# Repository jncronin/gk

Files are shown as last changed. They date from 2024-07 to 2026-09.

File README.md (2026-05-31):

# gk and gkos #

This respository provides PCB schematics, firmware and debugging support for the gkv4 handheld game console and its operating system, gkos.  For the original STM32H7S7-based gk, see [README-v3.md](README-v3.md).

gkv4 represents a significant upgrade over the original gk with improved speed, a bigger screen, more gamepad buttons and hardware-accelerated 3D rendering.

[Videos of the gkv4 in action](https://www.youtube.com/playlist?list=PLvXUUReQ2h1UtwOlHrIKgTddPxBIt5pAU)

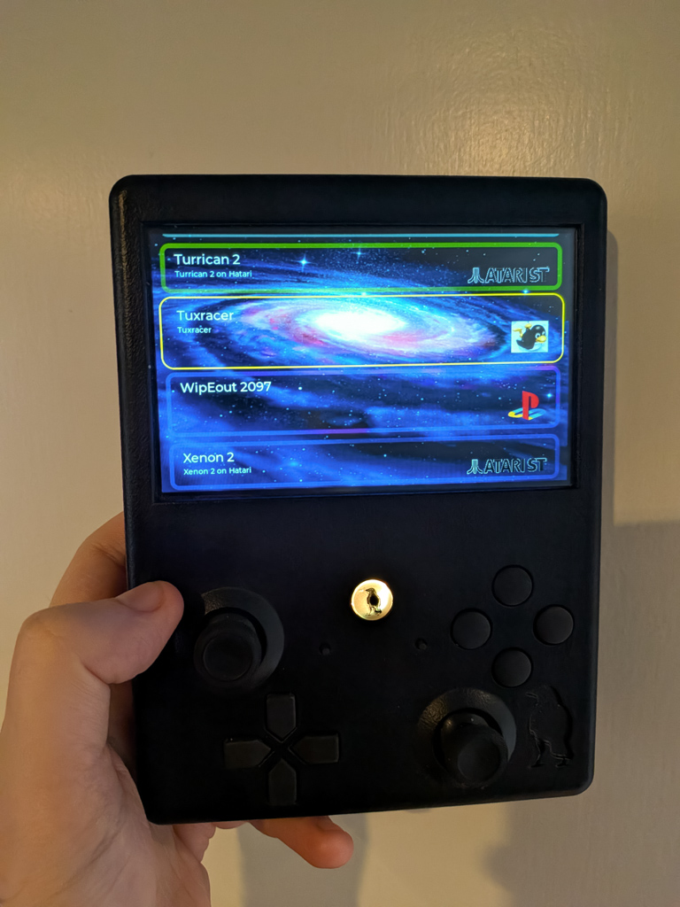
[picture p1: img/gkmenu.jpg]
An image of the gk showing its menu screen


## Overview ##

gkv4 is a small, battery powered handheld gaming console running on a STM32MP2 MPU (dual Cortex-A35 cores with additional Cortex-M33 core).  It runs a custom OS called gkos which allows near-instantaneous (MCU-like) cold boot times but is powerful enough to run most POSIX userspace applications.  See <https://github.com/jncronin/gk-userland> for the userland support including cross GCC toolchains and useful libraries.

Game/emulator support:
- Mednafen for NES, SNES, SMS, MD and Lynx support
- Hatari for Atari ST
- PCSX_rearmed for PS1
- Mupen64plus (see fork at <https://github.com/jncronin/mupen64-combined>) for N64 (GPU-accelerated)
- Atari++ for Atari XL
- DOSBox-X (achieves 25000 cycles/second, 199561 parrots, 74 XT on speedtst.com, roughly 486 50 MHz equivalent)
- Native ports of:
    - Neverball/neverputt (GPU-accelerated with tilt support)
    - Tuxracer (GPU-accelerated)
    - Doom (sdl2-doom)
    - Quake (ChocolateQuake)
    - Descent (ChocolateDescent)
    - koules

## Hardware Specifications ##

PCBs, schematics and case STL files are available in <https://github.com/jncronin/gk/tree/main/gk-pcbv4>.

- STM32MP255D processor with variable clock rate (defined on a per-game basis).  Debug and trace ports exposed.
- LPDDR4 RAM (1 GiB in current version)
- Lithium ion battery (10,000 mAH in current version) with USB-C charging via BQ25601, state of charge monitoring via MAX17048 and current sensing via INA236
- 800x480 5 inch touchscreen (ER-TFT050-6).  Hardware scaling support via STM32MP2 LTDC peripheral.
- Micro SD for storage with voltage switch support
- Wifi/Bluetooth module attached via M.2 E-key interface (e.g. EAR00389 module)
- Gyrometer/accelerometer + optional magnetometer for tilt interface
- Headphone + internal speaker audio out via TAD5112
- Multiple controls including:
    - Left and right analog sticks (programmable as digital on per-game basis)
    - ABXY + DPAD buttons
    - Start + select buttons
    - Analog throttle controller
    - Volume up/down (can be programmed as additional game inputs)
    - Menu button (opens OSD)
    - Left/right trigger + bumper buttons on back of device
- Battery backup for RTC

Total current draw is heavily dependent on screen brightness but is typically 1.5W or less at full CPU + GPU load with medium brightness, and max ~2W at full brightness.

## Software ##

gkos is a custom OS written from scratch in C++.  It is available in the <https://github.com/jncronin/gk/tree/main/Firmware-v4> directory.  Features:

- Armv8-A SMP scheduler with multiple active processes + threads
- Syscall interface with wrappers for most POSIX functions
- High resolution (10 ns precision) timer provided to games
- pthread support including threads, mutexes, semaphores, conditions, rwlocks and barriers
- A port of the etnaviv GPU driver allowing hardware-accelerated OpenGL
- Driver for Infineon CYW43439 chipset and IPv4 network stack
- SD card (with UHS-I mode support) with Ext4 (Lwext4) and FAT (fatfs) drivers
- USB driver allowing the device to present itself as a mass storage device to allow provisioning the internal SD card
- Offloading of all input tasks, including tilt sensor and touch screen filtering, to Cortex-M33 core

## Examples

Tuxracer using the GPU for rendering:

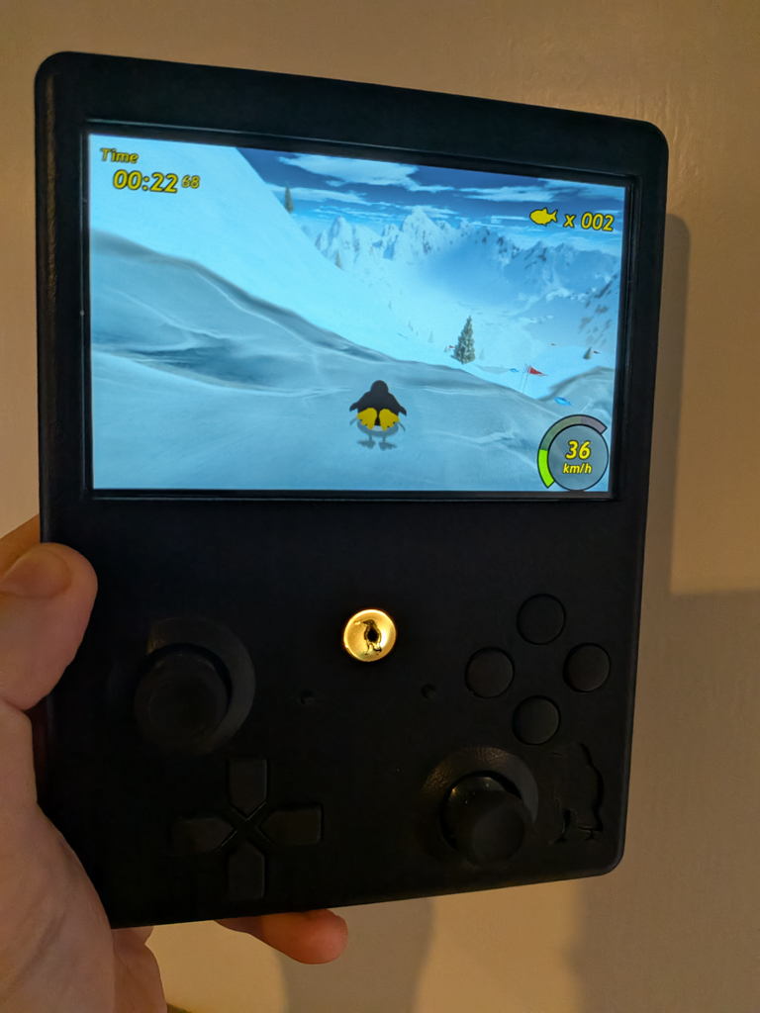
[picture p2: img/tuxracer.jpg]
Tuxracer on the GK


Tuxracer with the OSD overlay (handled by the gk-supervisor process in the (https://github.com/jncronin/gk-userland) repo) showing current system health, battery and cpu usage:

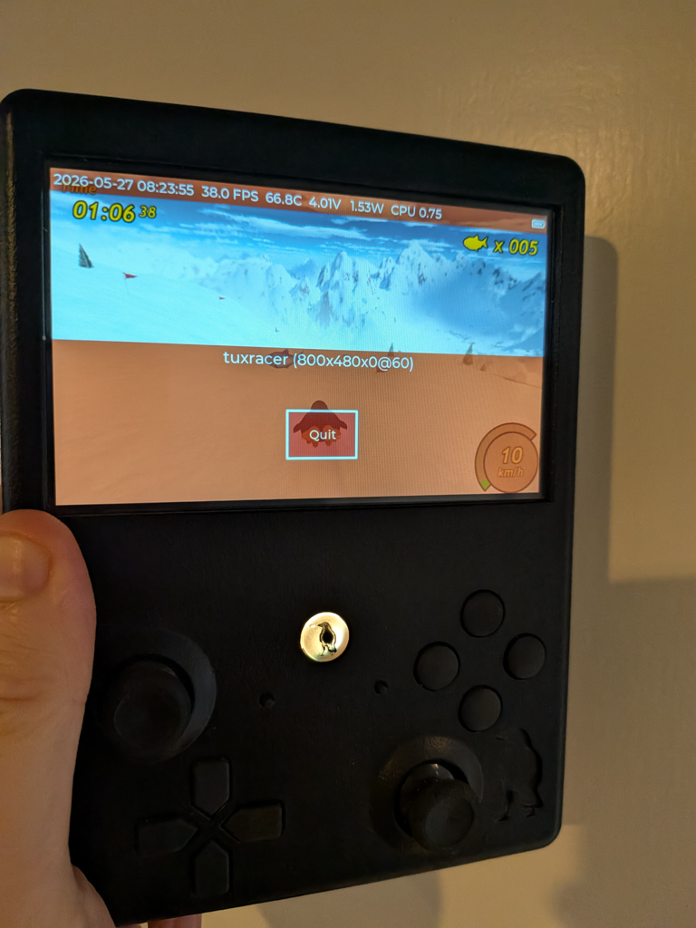
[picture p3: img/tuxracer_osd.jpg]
Tuxracer with on-screen display


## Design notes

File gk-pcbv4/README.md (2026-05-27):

# gkv4 PCBs #

This directory contains PDF schematics, KiCAD projects and Gerbers for the gkv4 PCBs.

There are 4 separate PCBs included:

- gk: This is the main board for the gkv4 and includes the high speed components.  It is implemented as a 6 layer board with impedance control requirements specified in the PCBnew file.
- pmic: This is a standalone 1 inch square board that contains the STPMIC25 power management chip and associated passive components.  It is implemented as a 4 layer board and additionally provided as a panelized board.  It is mounted using LGA/castellated holes onto the main board.
- controls: This is a daughter board containing the bulk of the controls for the front of the gk.  It aligns using M3 bolt holes with the main board and sits in front of it to ensure the thumb sticks are at the appropriate height relative to the screen.  It connects to the main board via a 2x10 pin 1.27mm pitch cable (ARM Cortex 20 pin Trace Cable).  It is a 2 layer PCB.
- controls-trigger: This is a single/two layer PCB simply containing the pads for the two back trigger buttons.  It is provided as a separate board to allow a certain amount of vertical separation from the controls board such that the triggers (which rotate rather than push) have better alignment with the pads.

For the various button pads a 5mm high rubber contact e.g. Xbox controller ABXY contact is expected.

Schematics, PCB designs and 3D models in this directory are Copyright (C) John Cronin 2024-2026 and released under the CERN-OHL-W license (see LICENSE in this directory).

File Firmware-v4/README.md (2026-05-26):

This directory contains the firmware for the V4 (STM32MP2) edition of gk

# Boot Sequence #
GKOSv4 comprises 5 separate binaries that are all stored on a 4 MiB QSPI flash chip on the board (W25Q32JV).  The boot sequence comprises the following:

## FSBL-A ##
The boot pins on the STM32MP2 are configured as 0100b i.e. Cortex-A35 master, Serial NOR boot.  A pushbutton is provided on BOOT3 to toggle this to 1100b i.e. Development boot if required.  This should only be required for the initial flashing of FSBL-A because this binary immediately opens debug access to the device.

The FSBL-A binary is loaded directly by the STM32MP2 BOOTROM.  It is located at the start of FLASH (0x60000000) and executes in SYSRAM at location 0x0e002600.  It is signed using the STM32 Signing Tool which codes this load address into its header.

The main roles of FSBL-A are to set up the UART6 as a debug log and then initialise the OCTOSPI1 peripheral to interface with the FLASH at 50 MHz QSPI.  It includes a short start-up delay to allow debugger attach, then it jumps to SSBL-A which executes directly from FLASH.

## SSBL-A ##
This contains the bulk of the pre-kernel init code.  It executes on the Cortex-A35 without the MMU enabled directly from the FLASH at address 0x60020000.  It's main roles are:
- Set CPU clock to use PLL at reasonable speed
- Set up a kernel timebase using TIM3 at 10 ns resolution
- Set up RIFSC to allow access to the various memories
- Determine the reason the gk turned on by polling the STPMIC25 chip - if it was an auto turn on due, e.g. to USB charging attach, then don't proceed to start the rest of the system, just switch off again.
- Enable DDR (load firmware, perform training etc)
- Load the EL3 secure monitor (secure_monitor) to DDR and set up a EL3 lower half address
- Enable MMU and jump to the secure monitor

## secure_monitor ##
This is a small stub designed to ease the transition from EL3 non-paged (SSBL-A) through EL3 paged through to EL1 paged (gkos proper).  It is linked to run at virtual offset 0x20000000 in the EL3 address space, and is loaded from FLASH at 0x60300000.  It is separated from SSBL-A (which is non-paged) simply to make linking the various binaries easier.  It's main role is to load gkos from FLASH into DDR, set up its pagine structures and execute it.  It creates a small data structure (gkos_boot_interface) that tells gkos how much DDR memory is left for it to use after the various uses for page tables by SSBL-A and secure_monitor, as well as handoff addresses for the TIM3 clock to ensure it remains monotonic through the boot process.  Finally, it provides a syscall for gkos to use to start the AP (throughout the boot process the AP is held in wait loops within the various loaders and passed on to the next whenever the MP does).

## gkos ##
This is the main kernel binary and runs at 0xffffffff80000000 in the upper half of the EL1 virtual address space.  It is loaded from FLASH at offset 0x60060000.

The gkos architecture is documented elsewhere but it also has a driver for the CM33 subsystem which it runs with the cm33_firmware.  gkos sets up the CM33 to run this directly from FLASH.

## cm33_firmware ##
This is firmware to run on the Cortex-M33 core within the STM32MP2.  It runs directly from FLASH at address 0x60380000.  It comprises FreeRTOS for threaded execution and is mainly concerned with input devices for the gk including all buttons with the exception of the power button (this is handled via direct interface to the STPMIC25 instead), the ADCs for the various thumbsticks etc, the touch screen and the tilt sensor.  It exposes a command buffer and register interface to gkos running on the CA35 and is able to offload the processing for these various input devices and provide real-time filtering, especially of the tilt sensor inputs.

## Summary ##

| firmware | FLASH location | FLASH max size | Execute location |
| --- | --- | --- | --- |
| FSBL-A | 0x6000 0000 | 128 kiB | SYSRAM, 0x0e002600 physical |
| SSBL-A | 0x6002 0000 | 256 kiB | FLASH,  0x60020000 physical |
| secure_monitor | 0x6030 0000 | 512 kiB | DDR, 0x20000000 EL3 virtual |
| gkos | 0x6006 0000 | 2688 kiB | DDR, 0xffffffff80000000 EL1 virtual |
| cm33_firmware  | 0x6038 0000 | 512 kiB | FLASH,  0x60380000 physical (on CM33)  |

# Directory layout #
The 5 above mentioned binaries exist in their own directories with the relevant CMakeLists.txt files within each.  Other relevant directories include:

- assets: contains artwork used during early boot by gkos and scripts to convert these to binaries
- cmake: toolchain files for building
- common-a: various files shared by the different binaries for example logging, spinlock management etc
- Infineon_AIROC...: driver for the Wifi/BT chip on gkos
- ospi_flasher: open flash programmer to allow the FLASH chip to be programmed
- stm32-ddr-phy-binary: the firmware for the DDR.  Used by SSBL-A.  Submodule from STMicroelectronics repository.
- STM32CubeMP2: CMSIS definitions for the chip.  Submodule from STMicroelectronics repository.
- unit_tests: host-side tests of various components of gkos.

Additionally, gkos v4 includes code from various components of the earlier gkos project in the Firmware directory including:
- gk-userlandinterface: syscall interface to the userland
- lwext4: Ext4 driver
- zlib: used for decompressing provisioning files

# License #
gkos v4 is Copyright (C) John Cronin 2024 - 2026 and released under the terms of the GPL v2 (see COPYING).  It includes third party code under the licenses in the relevant subdirectories which remain the copyright of their respective authors.

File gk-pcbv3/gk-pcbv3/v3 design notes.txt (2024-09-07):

CPU:
STM32H7S7L8H6H HEXA - 225 BGA

Memory:
hexa spi 512 Mbit plus __1.8V__
e.g. 2x Infineon S80KS5122GABHI020 512 Mbit/1.8V/200 MHz - 32 mA max x2 = 64 mA

Flash:
Octa SPI
e.g. Infineon S26KS128SDPBHI020 128 Mbit/1.8V/166 MHz - 180 mA max

Vreg:
buck-boost:
MAX77859 from Vlith -> 3.3V
Switch with VUSB separate V12V stepdown

SD 3.3V: use switch (do not support low voltage SD)

1.8V - need ~250 mA => 0.4W dropout
Can use MIC5504-1.8V SOT package -> max 253C/W rise = 101C... - but max and with sufficient PCB heat sink is okay

Use internal buck+LDO on STM32 for vcore

Or: LTC3380 - I2C controllable
initial feedback for LTC3380 is 0.725V, controllable from
     0.4125 to 0.8000 V in 0.0125 steps

For VCORE need initial ~1.25V - Divider 412k (lower)/301k (upper) (total 713k) gives VCORE 1.255V
0.8V FB gives 1.384V - satisfactory

For SVOS low - need ~0.74V: 0.4250V FB gives 0.7355V - satisfactory
For SVOS high - need ~1V: 0.5750 FB gives 0.995V - satisfactory

LCD:
DPI LTDC as per v1
LED boost regulator off VREGIN

Clock multiplier for 320x240->640x480 scaling:
Renesas 570BLF

Clock mux:
SN4559-Q1 or TMUX1237

Audio:
PLL1707 via TMUX1237 into I2S_CKIN
Out to PCM1753 and v2 filter stage/output amp

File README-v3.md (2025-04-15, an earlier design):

# gk and gkos #

This respository provides PCB schematics, firmware and debugging support for the gk handheld game console and its operating system, gkos.

## Overview ##

gk is a small, battery powered handheld gaming console running on an MCU (STM32H7S7) running at 600 MHz coupled to 128 MiB of XSPI SDRAM.  It has a 640x480 pixel 24-bit colour touchscreen, audio output (headphones/builtin speaker), accelerometer/gyrometer for tilt detection, USB interface for provisioning and WiFi network support.

The KiCAD schematics and case STL files are available in the gk-pcbv3 directory.

The firmware (gkos) is available in the Firmware directory and further documented in Firmware/doc

Despite being just a microcontroller, gk is able to run many native games at more-than-acceptable framerates including a PacMan clone (https://github.com/ebuc99/pacman), sdl2-doom (https://github.com/AlexOberhofer/sdl2-doom), QuakeGeneric (https://github.com/erysdren/quakegeneric), ChocolateDescent (https://github.com/InsanityBringer/ChocolateDescent), Red Alert SDL (https://github.com/Daft-Freak/CnC_and_Red_Alert/tree/main) as well as playable versions of Mesa software-rendered 3D games including Tux Racer (https://tuxracer.sourceforge.net/).  It also supports emulation - Mednafen (https://mednafen.github.io/) Atari Lynx, GameBoy, NES and Sega Master System and SNES modules all run at >= 20 frames per second (simpler ones at 60).  The Hatari emulator (https://hatari.tuxfamily.org/) is also supported.

Other relevant repositories include the gkos userspace toolchain and libraries (https://github.com/jncronin/gk-userland) which also contains the "gk-menu" process which displays a list of games, and the userland interface (https://github.com/jncronin/gk-userlandinterface) which contains simple defines/structures that are used to communicate between the userland and the kernel.

## Examples ##

An example [video](https://youtu.be/_2ip4UrAZJk) of the gk in action.

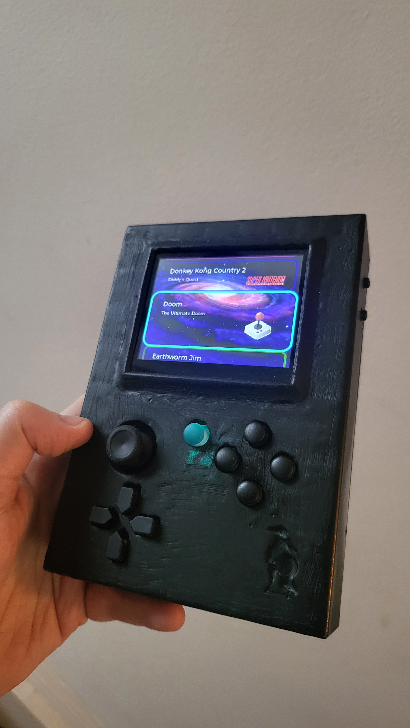
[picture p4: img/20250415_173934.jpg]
An example of the gk

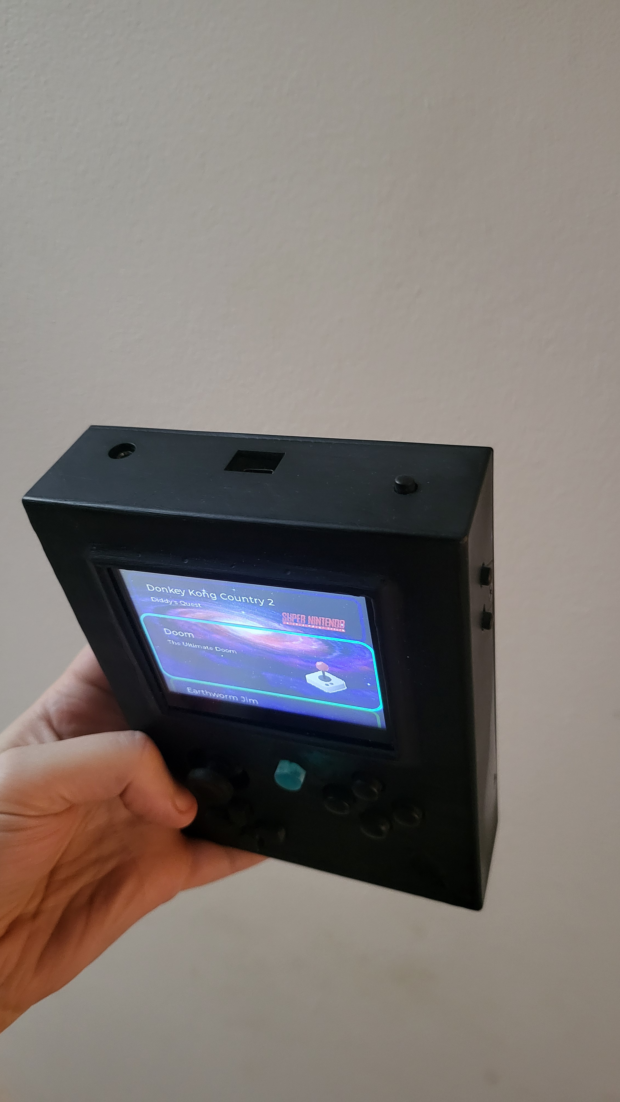
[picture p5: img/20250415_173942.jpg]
Another example of the gk


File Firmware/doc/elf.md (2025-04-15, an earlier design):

# gkos elf loading #

The MCU used in the gk does not have an MMU i.e. virtual memory support.  It does have an MPU to stop processes accessing other processes' data however there is no simple way to run two binaries linked to the same address.

To circumvent this, gkos uses some linker tricks for usermode programs.  All binaries are statically linked to address 0 and are linked with relocations emitted (ld --emit-relocs/-q option).  At load time (elf_load_fildes() in src/elf.cpp) the size of the combined .text/.data/.rodata section is determined and a memory block of the appropriate size requested.  This can be anywhere in memory but is typically in either AXISRAM or SDRAM due to size constraints.  The executable is then copied there.  By copying the entire executable en bloc all relative relocations are preserved.  The loader then goes through and patches up any absolute relocations by adding on the appropriate base address.

As a further complication, gkos supports the GCC \_\_attribute((hot))\_\_ label to speed up frequently used code tags.  The arm-none-gkos-ld linker places all these sections near the start of the .text section between tags \_\_start\_hot and \_\_end\_hot so they can be found by the loader.  If possible, this section is loaded to ITCM, AXISRAM or SRAM in that order to speed up code execution (loading from SDRAM is relatively slow despite the M7 D-cache).  The problem with this is that relative relocations either from/to the hot section (but not within it) also need to be patched, and ARM Thumb relocations are typically limited to +/- 23 bits for relative relocations.  Given ITCM is at 0x0 in the address map and SDRAM is at 0x90000000 this is not directly possible there trampoline/veneer code is also emitted to support this.

Finally, TLS sections are handled.  The address of the TLS 'template' is stored in the process structure, and then on thread creation this is copied to a new section available per-thread.  To speed up access to the thread pointer in userspace (LE32 access is used using a soft frame pointer), the current thread TLS block address is always available at address 0x58004518.

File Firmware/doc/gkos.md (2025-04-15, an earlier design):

# gkos #

This is the main documentation file for the gk operating system, gkos.

Whilst being developed for a MCU, gkos is not a real-time operating system but rather a general purpose multiprocessor multitasking operating system.  It has support for synchronization primitives, processes, threads, memory block allocation and inter-process memory protection, a virtual file system and networking.  It provides serializing drivers for the USB, SD, graphics and audio capabilities built into the STM32H7S7 chip, as well as WiFi networking through an externally connected ATWILC3000 module.

It has an extensive collection of userspace libraries, including a custom GCC toolchain, available at https://github.com/jncronin/gk-userland.  Notable userspace libraries include pthreads, SDL(1+2), Mesa, TCL, LVGL, the Squirrel scripting language and several audio libraries for both waveform and MIDI music.

The kernel is configured by the gk_conf.h configuration file.

Further documentation is provided within this directory regarding the relevant subsystems.

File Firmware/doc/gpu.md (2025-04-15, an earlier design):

# gkos GPU driver #

The STM32H7S7 chip has a built in DMA2D peripheral that supports hardware accelerated image and solid colour blitting.  Additionally it has a RGB LED controller (LTDC) that supports two layers.

The gpu code runs on a separate thread and processes messages received in an queue from other threads.  Thus, it is able to serialize and control thread's accesses to these three hardware components.

The default resolution of the gk is 640x480 with support for indexed, 16-bit and 24-bit colour.  The gpu driver has built-in double buffering so the next frame can be drawn whilst the current one is being displayed.  Only when the new frame is complete is the LTDC updated to show the new frame.  Drawing then occurs back on the old frame.  By default the framebuffer's MPU attributes are write-through.

Applications can use the framebuffer in many ways depending on how they are written.  Direct framebuffer access is exposed to applications and an API provides a buffer swap mechanism and returns the address of the new backbuffer.  This is used, for example, in SDL code using the "Surface" method of rendering.  In which case, the only messages which need to be passed to the gpu thread are FlipBuffers and SignalThread (the latter wakes up a waiting thread once gpu processing is complete and is useful, for example, to signal a waiting thread that the gpu is ready for the next frame to be drawn).

Alternatively they can use a rendering interface via BlitColor, BlitImage and BlitImageNoBlend calls.  These will use the hardware DMA engines to directly write either from memory to the framebuffer or from memory to memory (useful for offscreen rendering).  These routines also support scaling.  In the absence of scaling the DMA2D is used as it also supports blending.  These gpu calls are directly used by SDL2's rendering interface.

Hardware upscaling from 320x240 to 640x480 is supported through use of the GFXMMU peripheral in the STM32H7S7 for vertical scaling, and an external pixel clock doubler (570BLF) for horizontal scaling.

LTDC Layer 2 is used exclusively by the "supervisor" process, which provides an overlay for interacting with the system, e.g. closing current process, volume and brightness controls and custom options dependent on the process which typically include load/save game functionality.

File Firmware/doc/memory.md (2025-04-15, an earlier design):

# gkos memory block allocation #

gkos uses the STM32H7S7 DTCM for its own internal data structures including the kernel malloc functions.  All synchronization primitives and process control blocks live in this region.

The rest of RAM (the internal AXISRAM, SRAM, ITCM, and external XSPI SDRAM) is divided up for processes using a buddy system (inc/buddy.h).  This means that returned memory blocks sizes are aligned up to a power of 2, and the returned block is aligned upon its size.  Whilst potentially wasteful, this is useful in that these alignments are required by the Cortex-M7 MPU.

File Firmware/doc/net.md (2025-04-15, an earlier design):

# gkos networking #

Networking support is currently a work-in-progress for gkos however the currently supported features are:
- USB RNDIS driver
- ATWILC3000 WiFi driver
- ARP
- ICMPv4 ping
- IPv4
- TCPv4
- userspace socket library
- userspace tftpd daemon
- userspace telnetd daemon
- in-kernel dhcpc client (used with WiFi driver)
- in-kernel dhcpd daemon (used with USB RNDIS driver)

see src/net_*.cpp for details

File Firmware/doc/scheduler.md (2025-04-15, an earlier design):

# gkos scheduler #

The gkos scheduler exists in the Scheduler class (scheduler.h/scheduler.cpp) with the assembly code task switcher in switcher.cpp.

The scheduler is a priority-based round-robin scheduler supporting priority inheritance.  Task switches are invoked upon the PendSV interrupt.  It is currently triggered by the Cortex-M Systick however an experimental tickless mode is also available.  The Yield() function also triggers the PendSV handler and is used extensively throughout the kernel (e.g. by blocking code or by code which unblocks a higher priority task).

Choice of next thread to execute occurs within the PendSV handler, therefore is ideally as fast as possible.  Also within this function is code that unblocks any currently waiting threads of a higher priority than the current thread.

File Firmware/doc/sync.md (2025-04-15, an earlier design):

# gkos synchonization primitives #

gkos provides standard synchronization primitives (spinlocks, mutexes, semaphores, conditions, queues etc) in inc/osmutex.h and src/mutex.cpp.

gkos does not have separate kernel threads for each userspace thread.  All kernel code, including syscalls, is run on a single MSP thread.  Therefore, task switches cannot occur within a syscall and must occur on return to user mode.  This means that some syscalls must run multiple times to obtain a mutex lock (although they will typically Yield() immediately on return from a _trylock() function if they didn't obtain the lock).  Process inheritance is also supported for mutexes - if a high priority task tries to lock a mutex owned by a lower priority task, then the mutex being waited upon is stored within the high priority task TCB and the task immediately Yield()s.  During the next task selection, the waiting high priority task has its timeslice used by the task holding the mutex instead.  Once the mutex is released, the lower priority thread (via a flag in the mutex) knows to Yield() so that the high priority task can run again.

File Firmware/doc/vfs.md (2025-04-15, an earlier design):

# gkos vfs #

The virtual file system in gkos is mostly built around the excellent Lwext (https://github.com/gkostka/lwext4).

The 'open' syscall (src/syscalls_filesys.cpp) interprets the path, checks for a valid free file number and then creates a object of a class which implements 'File' (inc/osfile.h).  This is either a usb serial device (/dev/ttyUSB0), Segger RTT debug dump (/dev/stdout/err/in), a named pipe or a Lwext file.  All these classes are defined in inc/osfile.h.  socket() also uses a similar mechanism to open a SocketFile object and bind it to an fd.  The relevant File object is then stored in the process (inc/process.h) open file table.

Any subsequent file operation syscall uses the inherited members of the File object previously created.  In the case of LwextFiles, these generate a request pushed to a queue which are implemented by the ext thread.  The ext thread simply calls the relevant lwext4 function and returns its result.  Various compilation-time checks are performes to ensure that the types/defines used by lwext4 are the same as those used by newlib in the gk userland.

As a final optimisation a LRU cache of fstat values is maintained reducing the need to load these from disk.  This cache is currently wiped on _any_ write access to the SD card.

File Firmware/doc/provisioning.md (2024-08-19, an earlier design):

# gkos provisioning #

gkos uses the ext4 filesystem internally on its SD card.  In order to allow simple provisioning, a FAT filesystem is also exported that the user can see directly as a USB mass storage device.  This allows the user to add files to the gk without having to unmount the internal ext4 device, connect it to their host computer and potentially find ext4 drivers for said computer.

The SD card block 0 returned to the host PC when connected as a USB mass storage device is alterered from what actually exists to hide the ext4 partition.  Read/writes to the ext4 partition sectors are also disabled.  This means the gk can continue running, loading and saving to the ext4 parition whilst also conencted and exporting a FAT filesystem to a host PC.  Thus, provisioning files (simple .tar.gz files) can be copied to the gk whilst it is running.

On gk startup, the FAT filesystem is checked for provisioning files.  If any are found, they are uncompressed and loaded onto the ext4 drive.  The provisioning file is then deleted from the FAT drive.  Only after this is the FAT filesystem exported again via USB.  Optionally, at provision time, a file from the ext4 filesystem can also be copied back to the FAT system (useful, for example, for accessing crash logs).  See fs_provision.cpp for details.

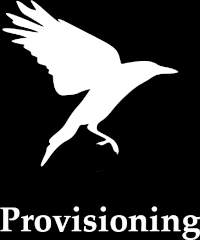
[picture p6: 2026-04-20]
Firmware-v4/assets/provisioning1.png

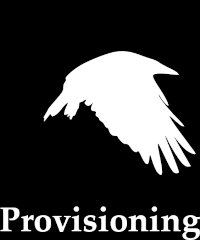
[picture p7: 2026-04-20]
Firmware-v4/assets/provisioning2.png

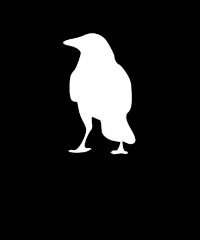
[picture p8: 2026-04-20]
Firmware-v4/assets/gk.png

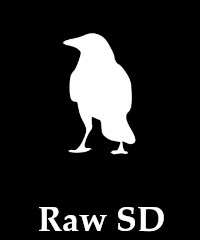
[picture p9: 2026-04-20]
Firmware-v4/assets/rawsd.png

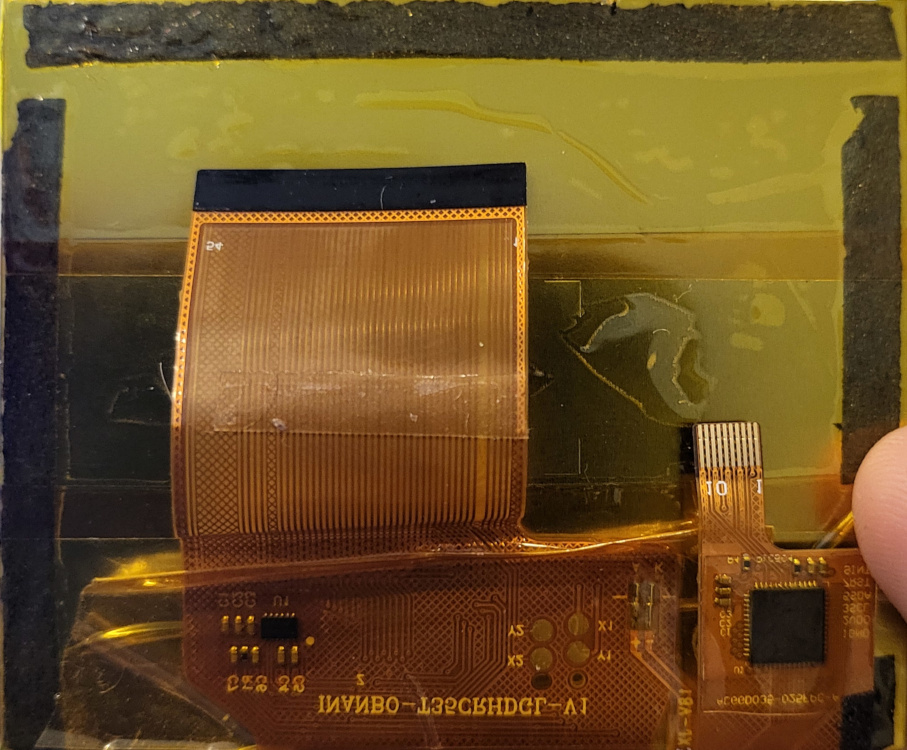
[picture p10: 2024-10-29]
gk-pcbv3/gk-pcbv3/screen_back.jpg

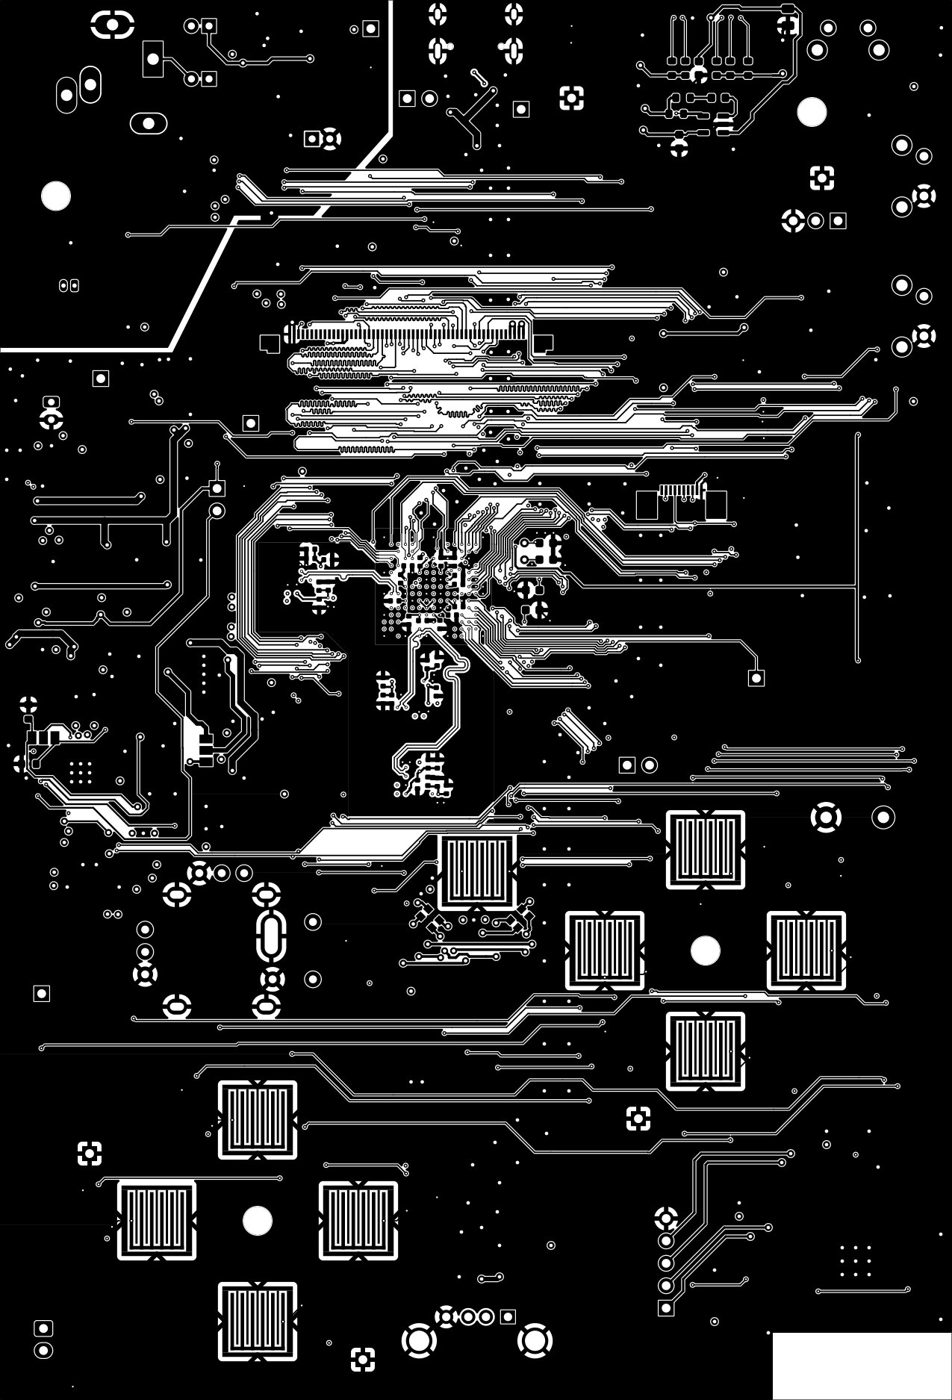
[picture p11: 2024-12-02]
gk-pcbv3/gk-pcbv3/gk-pcbv3-F_Cu.png

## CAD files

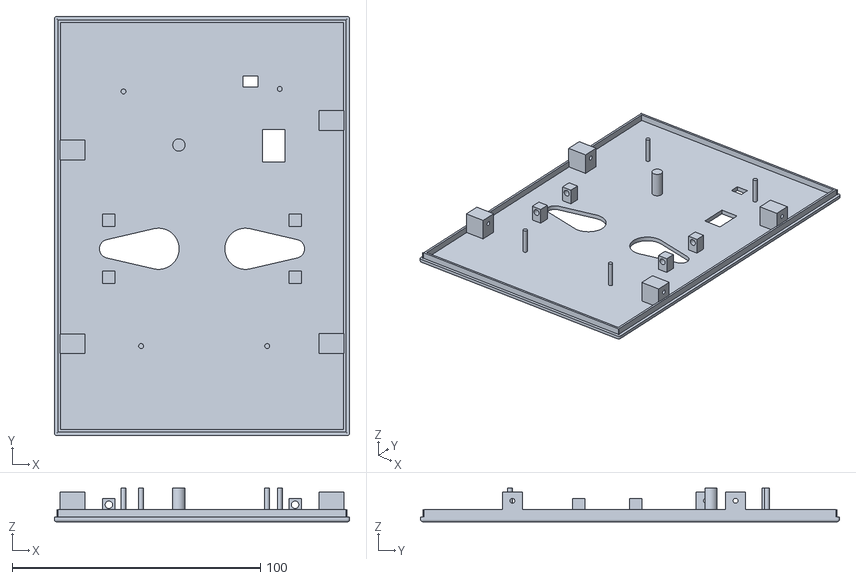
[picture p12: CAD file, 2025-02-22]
gk-pcbv3/gk-pcbv3/bottom panel.stl
119.0 x 168.9 x 13.6

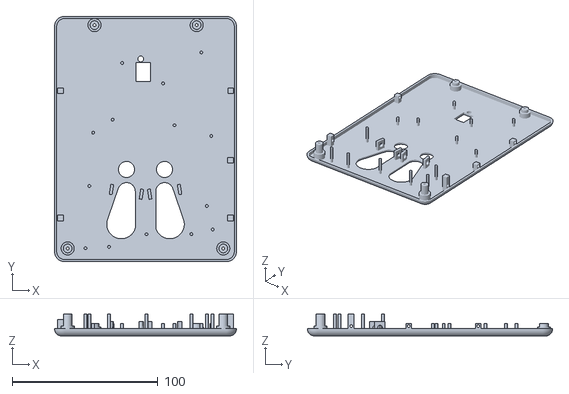
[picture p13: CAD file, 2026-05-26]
gk-pcbv4/gk/gkv4_case_bottom.stl
124.7 x 168.1 x 15.1

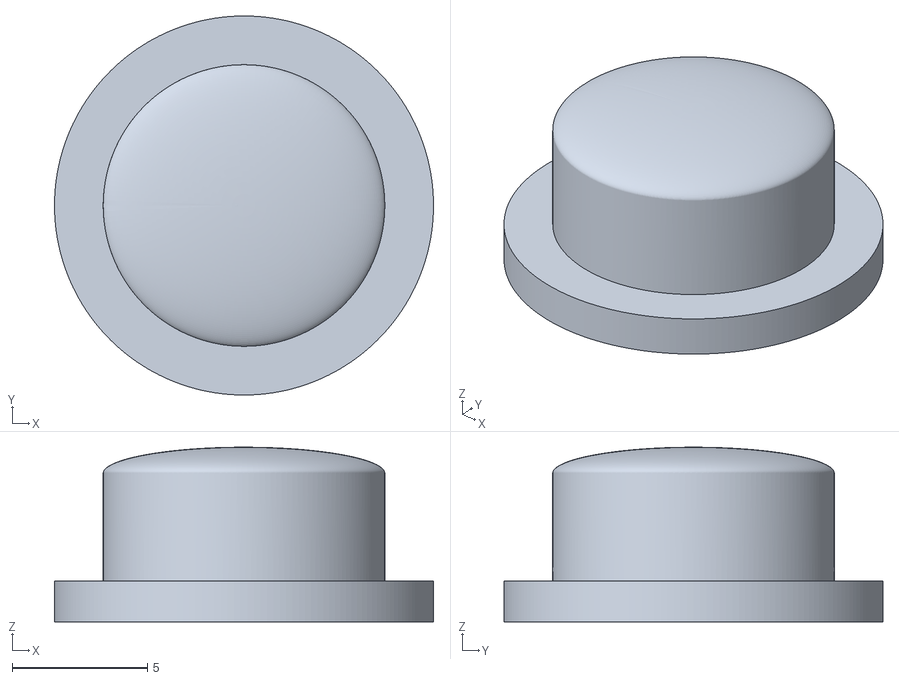
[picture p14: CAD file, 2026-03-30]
gk-pcbv4/stls/buttons/back_button.stl
14.0 x 14.0 x 6.45

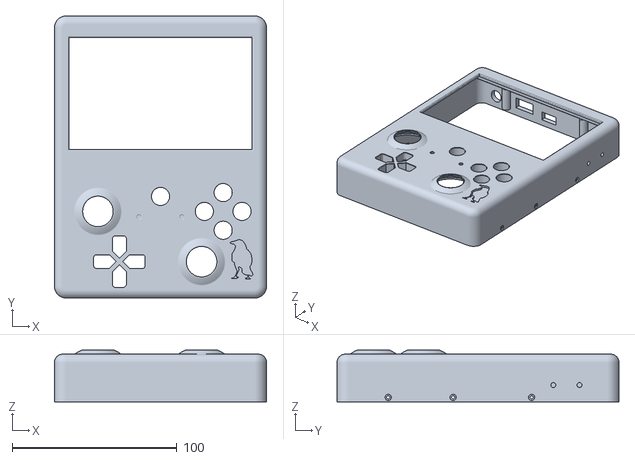
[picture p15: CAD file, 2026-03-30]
gk-pcbv4/stls/gkv4-top.stl
128.7 x 171.1 x 31.4

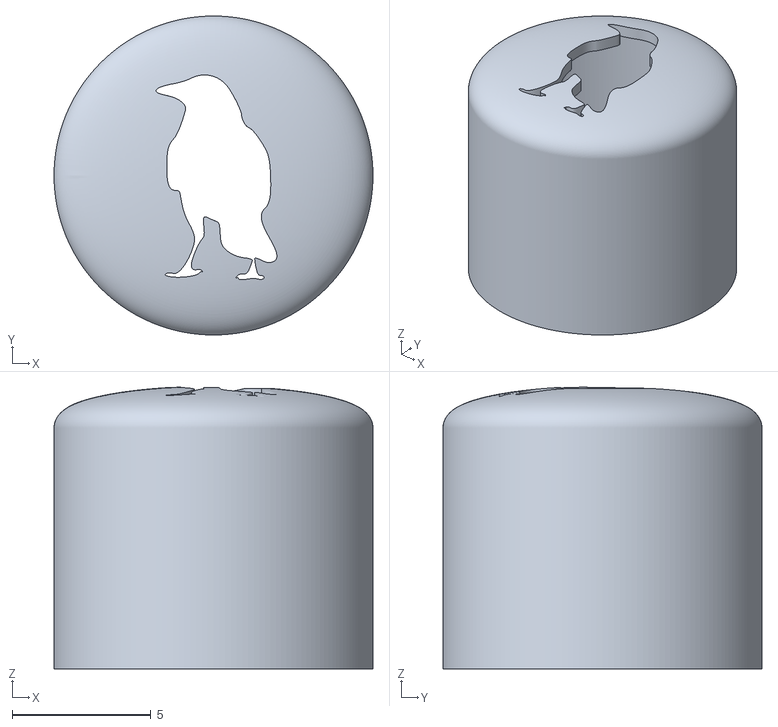
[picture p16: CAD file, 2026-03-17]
gk-pcbv4/stls/menu inlay/front_button_crow_mask.stl
11.5 x 11.5 x 10.2

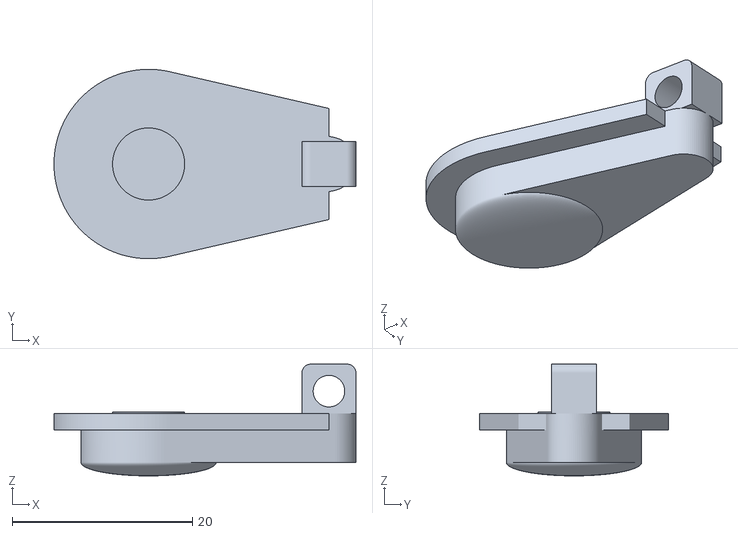
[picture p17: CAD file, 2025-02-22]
gk-pcbv3/gk-pcbv3/bumper button.stl
33.5 x 21.0 x 12.4

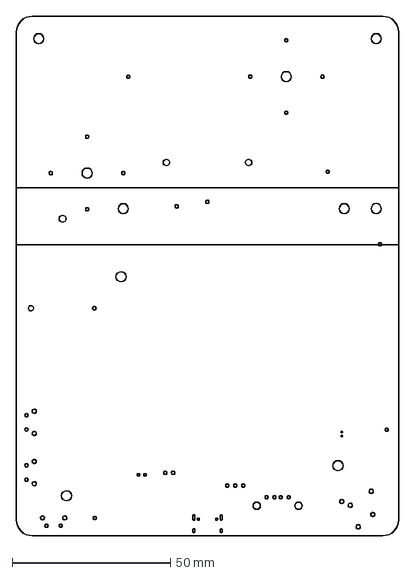
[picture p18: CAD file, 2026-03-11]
gk-pcbv4/gk-controls/v2_controls_for_export.dxf
120.7 x 164.1 mm

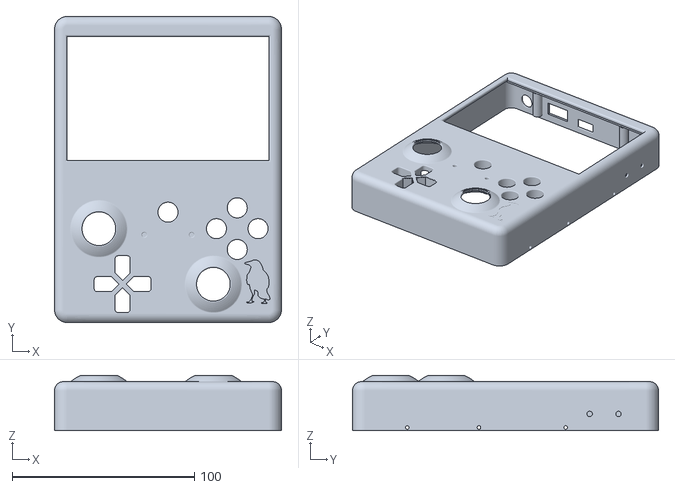
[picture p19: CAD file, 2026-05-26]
gk-pcbv4/gk/gkv4_case_top.stl
124.7 x 168.1 x 30.4

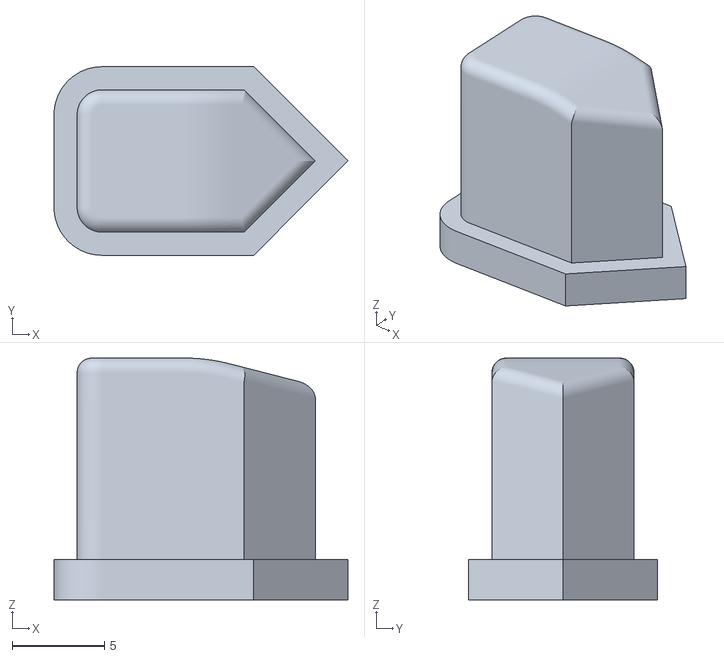
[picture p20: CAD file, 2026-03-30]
gk-pcbv4/stls/buttons/dpad.stl
15.9 x 10.2 x 13.1

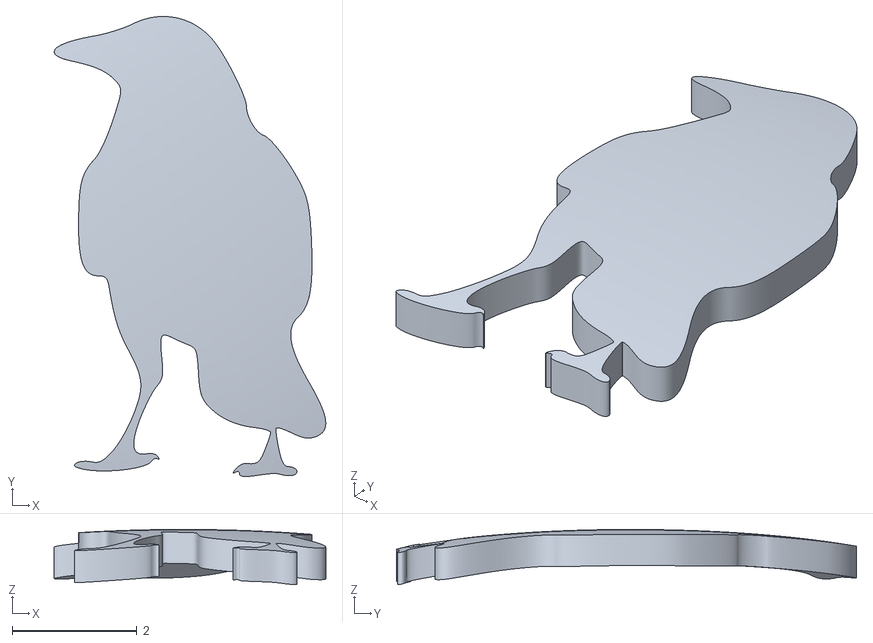
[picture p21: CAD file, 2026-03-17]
gk-pcbv4/stls/menu inlay/front_button_crow_inlay.stl
4.36 x 7.38 x 0.885

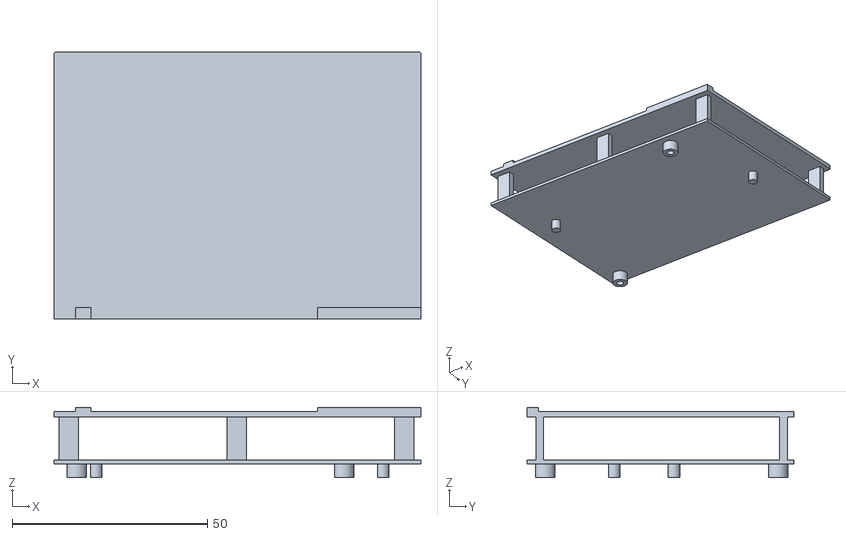
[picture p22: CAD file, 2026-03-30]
gk-pcbv4/stls/screen_support_v4.stl
94.0 x 68.5 x 17.9

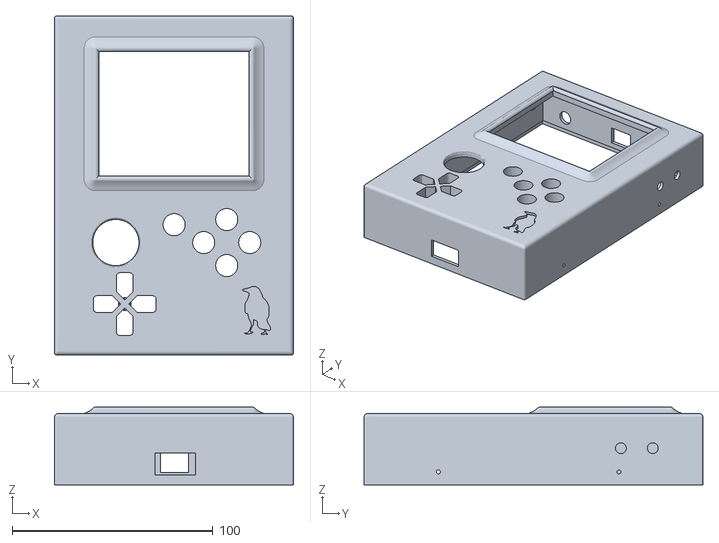
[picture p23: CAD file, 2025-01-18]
gk-pcbv3/gk-pcbv3/top panel.stl
119.0 x 168.9 x 38.8

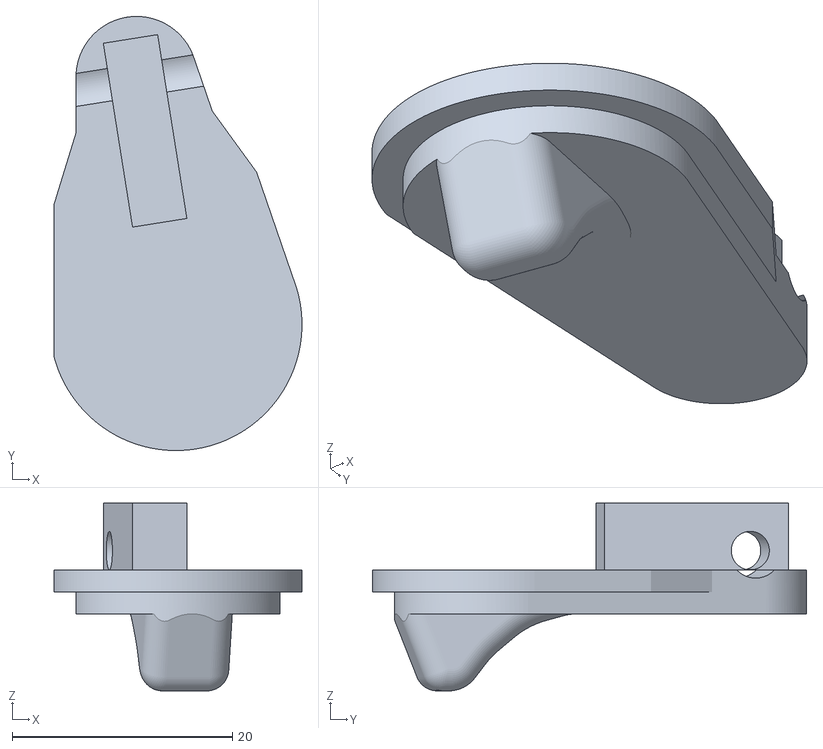
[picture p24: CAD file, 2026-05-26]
gk-pcbv4/gk/button_trigger.stl
22.5 x 39.4 x 17.1

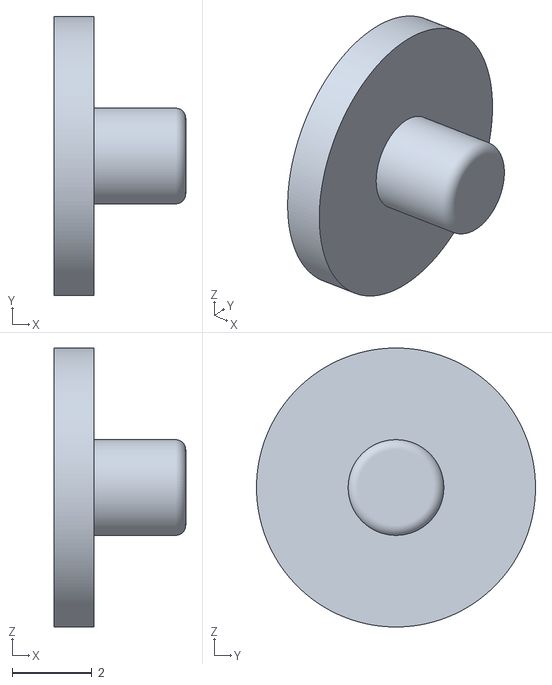
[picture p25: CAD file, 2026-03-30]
gk-pcbv4/stls/buttons/power_button.stl
3.30 x 7.00 x 7.00

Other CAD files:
gk-pcbv4/gk-controls-trigger/gk-controls-trigger.step
gk-pcbv4/gk-controls/gk-controls.step
gk-pcbv4/stls/gkv4-bottom.stl
gk-pcbv4/stls/menu inlay/front_button_crow_mask_top.stl
gk-pcbv3/gk-pcbv3/button power.stl
gk-pcbv3/gk-pcbv3/button x.stl
gk-pcbv3/gk-pcbv3/dpad left.stl
gk-pcbv3/gk-pcbv3/dpad.stl
gk-pcbv3/gk-pcbv3/screen support.stl
gk-pcbv4/gk/button_back.stl
gk-pcbv4/gk/button_dpad.stl
gk-pcbv4/gk/button_front.stl
gk-pcbv4/gk/button_side.stl
gk-pcbv4/gk/button_start_select.stl
gk-pcbv4/gk/gk.step
gk-pcbv4/gk/screen_support_v4.stl
gk-pcbv4/gk/v2 pcb outline.dxf
gk-pcbv4/stls/buttons/abxy_button.stl
gk-pcbv4/stls/buttons/menu_button.stl
gk-pcbv4/stls/buttons/menu_button_with_inlay.stl
gk-pcbv4/stls/buttons/side_button.stl
gk-pcbv4/stls/buttons/start_select.stl
gk-pcbv4/stls/buttons/trigger.stl

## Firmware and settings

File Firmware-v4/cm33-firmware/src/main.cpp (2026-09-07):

#include <stm32mp2xx.h>
#include "pins.h"
#include "debounce.h"
#include "_gk_proccreate.h"
#include "i2c.h"
#include "clocks.h"
#include "adc.h"
#include "lsm.h"
#include "guard.h"
#include "logger.h"

#include <cmath>

#include "FreeRTOS.h"
#include "task.h"

#include "ctp.h"

#include "interface/cm33_data.h"

__attribute__((section(".sram1"))) cm33_data_userspace d;
__attribute__((section(".sram2_header"))) cm33_data_kernel dk;

const pin BTN_MCU_VOLUP { GPIOH, 2 };
const pin BTN_MCU_VOLDOWN { GPIOJ, 0 };
const pin BTN_MCU_RB { GPIOB, 10 };
const pin BTN_MCU_LB { GPIOB, 0 };

const uint32_t rb_size = 256;
__attribute__((section(".sram2"))) volatile uint32_t rb[rb_size];

uint32_t adc_vals[5];
int lsm_ret = 0;
unsigned int ioexp_keystate = 0xffffffffU;  // default is all non-pressed

volatile bool ticked = false;
static void tick();

static float mouse_dx = 0.0f;
static float mouse_dy = 0.0f;
static const float mouse_max_1s = 512.0f;
static const int tick_freq = 200;
static const float mouse_scale_per_tick = mouse_max_1s / (float)tick_freq / 32768.0f;
static const int mouse_freq = 25;
static const int mouse_ticks = tick_freq / mouse_freq;

TaskHandle_t task_readsensors = nullptr;

void send_message(uint32_t msg);

class ioexp_pin
{
    public:
        unsigned int v;
        ioexp_pin(unsigned int _v) : v(_v) {}
        bool value() const
        {
            if(ioexp_keystate & v)
                return true;
            else
                return false;
        }
};

/* This maps a pair of joystick axes (X,Y) to a digital 8-way stick


    There is a circular deadzone in the middle.  Then we divide up the outer
    region into 8 segments: UP, UP/RIGHT, RIGHT etc
    Each segment is 45 degrees so the dividing lines are at 22.5, 67.5 etc degrees.

    The result is then passed through a debouncer (joy_pin) below.
*/
class digi_joy
{
    public:
        const int16_t *x, *y;
        int16_t deadzone;
        float dz_sq;
        float dist;
        float ang;
        unsigned int btns = 0U; // L, R, U, D
        static const unsigned int left = 1U << 0;
        static const unsigned int right = 1U << 1;
        static const unsigned int up = 1U << 2;
        static const unsigned int down = 1U << 3;
        bool no_diagonals = false;

        digi_joy(const int16_t *_x, const int16_t *_y, int16_t _deadzone = 8000) :
            x(_x), y(_y)
        {
            set_deadzone(_deadzone);
        }

        void set_deadzone(int16_t _deadzone)
        {
            deadzone = _deadzone;
            dz_sq = (float)(int)_deadzone * (float)(int)_deadzone;
        }

        void tick()
        {
            auto cx = (float)(int)*x;
            auto cy = (float)(int)*y;

            dist = cx * cx + cy * cy;
            if(dist < dz_sq)
            {
                btns = 0;
                return;
            }

            // up is encoded as negative y, left as negative x - correct for this for typical
            //  cartesian coordinates
            ang = std::atan2(-cy, cx);

            // check all angles
            if(!no_diagonals)
            {
                // check all 8 possible directions
                if(ang > (float)M_PI * 7.0f / 8.0f)
                {
                    btns = left;
                }
                else if(ang > (float)M_PI * 5.0f / 8.0f)
                {
                    btns = left | up;
                }
                else if(ang > (float)M_PI * 3.0f / 8.0f)
                {
                    btns = up;
                }
                else if(ang > (float)M_PI * 1.0f / 8.0f)
                {
                    btns = right | up;
                }
                else if(ang > (float)M_PI * -1.0f / 8.0f)
                {
                    btns = right;
                }
                else if(ang > (float)M_PI * -3.0f / 8.0f)
                {
                    btns = right | down;
                }
                else if(ang > (float)M_PI * -5.0f / 8.0f)
                {
                    btns = down;
                }
                else if(ang > (float)M_PI * -7.0f / 8.0f)
                {
                    btns = left | down;
                }
                else
                {
                    btns = left;
                }
            }
            else
            {
                // just check up/down/left/right i.e. 90 degree segments
                if(ang > (float)M_PI * 3.0f / 4.0f)
                {
                    btns = left;
                }
                else if(ang > (float)M_PI * 1.0f / 4.0f)
                {
                    btns = up;
                }
                else if(ang > (float)M_PI * -1.0f / 4.0f)
                {
                    btns = right;
                }
                else if(ang > (float)M_PI * -3.0f / 4.0f)
                {
                    btns = down;
                }
                else
                {
                    btns = left;
                }
            }
        }
};

class joy_pin
{
    public:
        const digi_joy &dj;
        unsigned int btn;

        joy_pin(const digi_joy &_dj, unsigned int _btn) : dj(_dj), btn(_btn) {}

        bool value() const
        {
            // pretend to be an active low output
            if(dj.btns & btn)
            {
                return false;
            }
            else
            {
                return true;
            }
        }
};

class throttle_detent
{
    protected:
        int last_val = 0;
        int ndetents = 0;

    public:
        int set_detents(int _ndetents)
        {
            ndetents = _ndetents;
            return 0;
        }

        int val_to_detent(int v)
        {
            /* For an example of 4 detents, we have detents centred on the following:
                0, 33, 66, 100
                
                The detent width is 100/(n-1) i.e. 33
                The 3 dividing lines are 16.6, 50, 83.3

                val to detent mapping therefore requires a shift:
                    (v + (detent_width / 2)) / detent_width
            */

            auto dwidth = 65536 / (ndetents - 1);
            return ((v + 32768) + dwidth / 2) / dwidth;
        }

        void tick(int new_val)
        {
            // register motion if we've moved a small amount from the last
            if(std::abs(last_val - new_val) < 1024)
                return;
            last_val = new_val;

            if(ndetents == 0)
                return;

            auto detent = val_to_detent(last_val);
            send_message(CM33_DK_MSG_PRESS | (GK_THROTTLE_DETENT_0 + detent));
            send_message(CM33_DK_MSG_RELEASE | (GK_THROTTLE_DETENT_0 + detent));
        }
};

const ioexp_pin BTN_MCU_A(1U << 0);
const ioexp_pin BTN_MCU_B(1U << 1);
const ioexp_pin BTN_MCU_X(1U << 2);
const ioexp_pin BTN_MCU_Y(1U << 3);
const ioexp_pin BTN_MCU_U(1U << 4);
const ioexp_pin BTN_MCU_D(1U << 5);
const ioexp_pin BTN_MCU_L(1U << 6);
const ioexp_pin BTN_MCU_R(1U << 7);
const ioexp_pin BTN_MCU_START(1U << 8);
const ioexp_pin BTN_MCU_SELECT(1U << 9);
const ioexp_pin BTN_MCU_LT(1U << 10);
const ioexp_pin BTN_MCU_RT(1U << 11);
const ioexp_pin BTN_MCU_JOY_A(1U << 12);
const ioexp_pin BTN_MCU_JOY_B(1U << 13);
const ioexp_pin BTN_MCU_MENU(1U << 14);

digi_joy dj_A((const int16_t *)&d.joy_a.x,
    (const int16_t *)&d.joy_a.y);
digi_joy dj_B((const int16_t *)&d.joy_b.x,
    (const int16_t *)&d.joy_b.y);
digi_joy dj_TILT((const int16_t *)&d.joy_tilt.x,
    (const int16_t *)&d.joy_tilt.y, 12000);

throttle_detent td;

const joy_pin JOY_A_LEFT(dj_A, digi_joy::left);
const joy_pin JOY_A_RIGHT(dj_A, digi_joy::right);
const joy_pin JOY_A_UP(dj_A, digi_joy::up);
const joy_pin JOY_A_DOWN(dj_A, digi_joy::down);

const joy_pin JOY_B_LEFT(dj_B, digi_joy::left);
const joy_pin JOY_B_RIGHT(dj_B, digi_joy::right);
const joy_pin JOY_B_UP(dj_B, digi_joy::up);
const joy_pin JOY_B_DOWN(dj_B, digi_joy::down);

const joy_pin JOY_TILT_LEFT(dj_TILT, digi_joy::left);
const joy_pin JOY_TILT_RIGHT(dj_TILT, digi_joy::right);
const joy_pin JOY_TILT_UP(dj_TILT, digi_joy::down);        // invert tilt for typical flight stick orientation
const joy_pin JOY_TILT_DOWN(dj_TILT, digi_joy::up);

Debounce db_VOLUP(BTN_MCU_VOLUP, GK_KEYVOLUP);
Debounce db_VOLDOWN(BTN_MCU_VOLDOWN, GK_KEYVOLDOWN);
Debounce db_LB(BTN_MCU_LB, GK_KEYLB);
Debounce db_RB(BTN_MCU_RB, GK_KEYRB);
Debounce db_A(BTN_MCU_A, GK_KEYA);
Debounce db_B(BTN_MCU_B, GK_KEYB);
Debounce db_X(BTN_MCU_X, GK_KEYX);
Debounce db_Y(BTN_MCU_Y, GK_KEYY);
Debounce db_U(BTN_MCU_U, GK_KEYUP);
Debounce db_D(BTN_MCU_D, GK_KEYDOWN);
Debounce db_L(BTN_MCU_L, GK_KEYLEFT);
Debounce db_R(BTN_MCU_R, GK_KEYRIGHT);
Debounce db_SELECT(BTN_MCU_SELECT, GK_KEYSELECT);
Debounce db_START(BTN_MCU_START, GK_KEYSTART);
Debounce db_LT(BTN_MCU_LT, GK_KEYLT);
Debounce db_RT(BTN_MCU_RT, GK_KEYRT);
Debounce db_JOYBTNA(BTN_MCU_JOY_A, GK_KEYJOY);
Debounce db_JOYBTNB(BTN_MCU_JOY_B, GK_KEYJOYB);
Debounce db_MENU(BTN_MCU_MENU, GK_KEYMENU);
Debounce db_JOY_A_LEFT(JOY_A_LEFT, GK_KEYJOYDIGILEFT);
Debounce db_JOY_A_RIGHT(JOY_A_RIGHT, GK_KEYJOYDIGIRIGHT);
Debounce db_JOY_A_UP(JOY_A_UP, GK_KEYJOYDIGIUP);
Debounce db_JOY_A_DOWN(JOY_A_DOWN, GK_KEYJOYDIGIDOWN);
Debounce db_JOY_B_LEFT(JOY_B_LEFT, GK_KEYJOYBDIGILEFT);
Debounce db_JOY_B_RIGHT(JOY_B_RIGHT, GK_KEYJOYBDIGIRIGHT);
Debounce db_JOY_B_UP(JOY_B_UP, GK_KEYJOYBDIGIUP);
Debounce db_JOY_B_DOWN(JOY_B_DOWN, GK_KEYJOYBDIGIDOWN);
Debounce db_JOY_TILT_LEFT(JOY_TILT_LEFT, GK_KEYTILTLEFT);
Debounce db_JOY_TILT_RIGHT(JOY_TILT_RIGHT, GK_KEYTILTRIGHT);
Debounce db_JOY_TILT_UP(JOY_TILT_UP, GK_KEYTILTUP);
Debounce db_JOY_TILT_DOWN(JOY_TILT_DOWN, GK_KEYTILTDOWN);

static void readsensors_task(void *);

int main()
{
    // load defaults
    dk.cr = 0;
    dk.sr = 0;
    dk.joy_a_calib.left = -32767;
    dk.joy_a_calib.right = 32767;
    dk.joy_a_calib.top = 32767;
    dk.joy_a_calib.bottom = -32767;
    dk.joy_a_calib.middle_x = 0;
    dk.joy_a_calib.middle_y = 0;
    dk.joy_a_calib.analog_dz = 1000;
    dk.joy_a_calib.digital_dz = 12000;
    dk.joy_b_calib.left = -32767;
    dk.joy_b_calib.right = 32767;
    dk.joy_b_calib.top = 32767;
    dk.joy_b_calib.bottom = -32767;
    dk.joy_b_calib.middle_x = 0;
    dk.joy_b_calib.middle_y = 0;
    dk.joy_b_calib.analog_dz = 1000;
    dk.joy_b_calib.digital_dz = 12000;
    dk.throttle_calib.left = -32767;
    dk.throttle_calib.right = 32767;
    dk.throttle_calib.top = 32767;
    dk.throttle_calib.bottom = -32767;
    dk.throttle_calib.middle_x = 0;
    dk.throttle_calib.middle_y = 0;
    dk.throttle_calib.analog_dz = 0;
    dk.throttle_calib.digital_dz = 0;
    dk.tilt_calib.left = -32767;
    dk.tilt_calib.right = 32767;
    dk.tilt_calib.top = 32767;
    dk.tilt_calib.bottom = -32767;
    dk.tilt_calib.middle_x = 0;
    dk.tilt_calib.middle_y = 0;
    dk.tilt_calib.analog_dz = 1000;
    dk.tilt_calib.digital_dz = 12000;
    dk.rb_r_ptr = 0;
    dk.rb_w_ptr = 0;
    dk.rb_size = rb_size;
    dk.rb_paddr = (uint32_t)(uintptr_t)rb;

    init_i2c();
    init_adc();
    init_lsm();

    // Timer
    RCC->TIM6CFGR |= RCC_TIM6CFGR_TIM6EN;
    RCC->TIM6CFGR &= ~RCC_TIM6CFGR_TIM6RST;
    (void)RCC->TIM6CFGR;

    // TIM6 clocks at 200 MHz, prescale to 5 MHz, then divide 25000 to get 200 Hz tick
    TIM6->CR1 = 0;
    TIM6->CR2 = 0;
    TIM6->SMCR = 0;
    TIM6->DIER = TIM_DIER_UIE;
    TIM6->CCMR1 = 0;
    TIM6->CCMR2 = 0;
    TIM6->CCMR3 = 0;
    TIM6->PSC = 40 - 1;
    TIM6->ARR = 24999;
    TIM6->CNT = 0;
    TIM6->CR1 = TIM_CR1_CEN;

    // report we are awake
    dk.sr = dk.sr | CM33_DK_SR_OUTPUT_ENABLE | CM33_DK_SR_READY;
    __SEV();

    NVIC_SetPriority(TIM6_IRQn, 8);     // check this - we have 4 priority bits
    NVIC_EnableIRQ(TIM6_IRQn);
    __enable_irq();

    xTaskCreate(readsensors_task, "sensors", 2048, nullptr, configMAX_PRIORITIES - 1,
        &task_readsensors);

    init_ctp();

    vTaskStartScheduler();
    while(true);

/*
    while(true)
    {
        __WFI();
        if(ticked)
        {
            tick();
        }
    } */
}

void readsensors_task(void *)
{
    while(true)
    {
        if(ulTaskNotifyTake(pdTRUE, portMAX_DELAY))
        {
            tick();
        }
    }
}

void send_message(uint32_t msg)
{
    UninterruptibleGuard ug;
    auto new_w_ptr = dk.rb_w_ptr + 1;
    if(new_w_ptr >= dk.rb_size)
        new_w_ptr = 0;
    if(new_w_ptr == dk.rb_r_ptr)
    {
        // out of space
        dk.sr = dk.sr | CM33_DK_SR_OVERFLOW;
        return;
    }
    rb[dk.rb_w_ptr] = msg;
    dk.rb_w_ptr = new_w_ptr;
}

template <class T> void db_tick(T &db, const char *dbg = nullptr)
{
    auto ret = db.tick();
    auto v = db.get_val();
    if(ret & pin_state::StableHigh)
    {
        d.keystate = d.keystate & ~(1U << v);
    }
    else if(ret & pin_state::StableLow)
    {
        d.keystate = d.keystate | (1U << v);
    }
    if(ret & pin_state::NewStableState)
    {
        if(ret & pin_state::StableHigh)
        {
            if(dbg) klog("Release: %s\n", dbg);
            send_message(CM33_DK_MSG_RELEASE| v);
        }
        else if(ret & pin_state::StableLow)
        {
            if(dbg) klog("Press: %s\n", dbg);
            send_message(CM33_DK_MSG_PRESS | v);
        }
    }
    if(ret & pin_state::StableLow)
    {
        if(ret & pin_state::LongPress)
        {
            if(dbg) klog("LongPress: %s\n", dbg);
            send_message(CM33_DK_MSG_LONGPRESS | v);
        }
        if(ret & pin_state::Repeat)
        {
            if(dbg) klog("Repeat: %s\n", dbg);
            send_message(CM33_DK_MSG_REPEAT | v);
        }
    }
} 

static int16_t joy_scale(uint32_t input, bool invert)
{
    int32_t i_input = (int32_t)input;
    i_input -= 8192;
    if(invert) i_input = -i_input;
    i_input *= 4;

    if(i_input < -32768) i_input = -32768;
    if(i_input > 32767) i_input = 32767;

    return (int16_t)i_input;
}

static int16_t joy_apply_calibration(int16_t in, 
    int16_t left, int16_t middle, int16_t right)
{
    // scale "in" to either between [left, middle] or [middle, right] such that left = -32768 and right = 32767
    if(in <= left)
        return -32768;
    else if(in == middle)
        return 0;
    else if(in >= right)
        return 32767;
    else
    {
        int32_t res;
        if(in < middle)
        {
            // scale [left, middle] to [-32767, 0]
            res = (int32_t)((float)(in - left) / (float)(middle - left) * 32767.0f - 32767.0f);
        }
        else
        {
            // scale [middle, right] to [0, 32767]
            res = (int32_t)((float)(in - middle) / (float)(right - middle) * 32767.0f);
        }
        if(res < -32768) res = -32768;
        if(res > 32767) res = 32767;
        return res;
    }
}

static void joy_apply_calibration(const volatile cm33_joystick *in,
    volatile cm33_joystick *out,
    const volatile cm33_joy_calib *calib = nullptr,
    bool squircle = false)
{
    out->res0 = 0;
    out->res1 = 0;
    if(!calib)
    {
        out->x = in->x;
        out->y = in->y;
        return;
    }

    auto x = joy_apply_calibration(in->x, calib->left, calib->middle_x, calib->right);
    auto y = joy_apply_calibration(in->y, calib->bottom, calib->middle_y, calib->top);

    if(squircle)
    {
        auto u = (float)x / 32768.0f;
        auto v = (float)y / 32768.0f;

        if(u > 1.0f) u = 1.0f;
        if(u < -1.0f) u = -1.0f;
        if(v > 1.0f) v = 1.0f;
        if(v < -1.0f) v = -1.0f;

        // https://squircular.blogspot.com/2015/09/mapping-circle-to-square.html

        // handle case where u2 + v2 > 1, which translates to a sqrt of negative number
        auto x2_a = 2.0f + 2.0f * u * (float)M_SQRT2 + u * u - v * v;
        auto x2_b = 2.0f - 2.0f * u * (float)M_SQRT2 + u * u - v * v;
        if(x2_a < 0.0f) x2_a = 0.0f;
        if(x2_b < 0.0f) x2_b = 0.0f;
        auto x2 = (int)((0.5f * std::sqrt(x2_a) - 0.5f * std::sqrt(x2_b)) * 32767.0f);

        auto y2_a = 2.0f + 2.0f * v * (float)M_SQRT2 - u * u + v * v;
        auto y2_b = 2.0f - 2.0f * v * (float)M_SQRT2 - u * u + v * v;
        if(y2_a < 0.0f) y2_a = 0.0f;
        if(y2_b < 0.0f) y2_b = 0.0f;
        auto y2 = (int)((0.5f * std::sqrt(y2_a) - 0.5f * std::sqrt(y2_b)) * 32767.0f);

        if(x2 > 32767) x2 = 32767;
        if(x2 < -32767) x2 = -32767;
        if(y2 > 32767) y2 = 32767;
        if(y2 < -32767) y2 = -32767;


        x = x2;
        y = y2;
    }

    // apply analog deadzone
    if(calib->analog_dz)
    {
        auto xsq = (int)x * (int)x;
        auto ysq = (int)y * (int)y;
        auto dzsq = (int)calib->analog_dz * (int)calib->analog_dz;

        if((xsq + ysq) < dzsq)
        {
            x = 0;
            y = 0;
        }
    }

    out->x = x;
    out->y = y;
}

static void joystick_tick()
{
    /* map joystick axes from raw adc to something interpretable by SDL and
        others

        JOY A X : adc_vals[0] left = 0, right = 16k
        JOY A Y : adc_vals[1] up = 16k, down = 0
        JOY B X : adc_vals[3] left = 0, right = 16k (actually about 12k - problem with switch itself)
        JOY B Y : adc_vals[2] up = 0, down = 16k

        scale to:
            X: left = -32k, right = +32k
            Y: down = -32k, up = +32k

        Add dead zone in the middle of 8k (after scaling and calibration), then pass through a debouncer for digital inputs */
    
    d.joy_a_raw.x = joy_scale(adc_vals[0] & 0x3fffU, false);
    d.joy_a_raw.y = joy_scale(adc_vals[1] & 0x3fffU, true);
    d.joy_b_raw.x = joy_scale(adc_vals[3] & 0x3fffU, false);
    d.joy_b_raw.y = joy_scale(adc_vals[2] & 0x3fffU, false);
    d.throttle_raw.x = 8192;
    d.throttle_raw.y = joy_scale(adc_vals[4] & 0x3fffU, false);

    joy_apply_calibration(&d.joy_a_raw, &d.joy_a, &dk.joy_a_calib, true);
    joy_apply_calibration(&d.joy_b_raw, &d.joy_b, &dk.joy_b_calib, true);
    joy_apply_calibration(&d.throttle_raw, &d.throttle, &dk.throttle_calib);

    dj_A.tick();
    dj_B.tick();
    dj_TILT.tick();
}
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

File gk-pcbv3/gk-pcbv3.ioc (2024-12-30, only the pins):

Mcu.UserName=STM32H7S7L8HxH
PA0.Signal=LTDC_G3
PA1.Signal=LTDC_G2
PA10.Signal=LTDC_B4
PA11.Signal=LTDC_B3
PA12.Signal=LTDC_B2
PA13(JTMS/SWDIO).Signal=DEBUG_JTMS-SWDIO
PA14(JTCK/SWCLK).Signal=DEBUG_JTCK-SWCLK
PA15(JTDI).Signal=LTDC_R5
PA2.Signal=LTDC_B7
PA3.Signal=LTDC_DE
PA4.Signal=SPI3_NSS
PA5.Signal=S_TIM2_CH1
PA6.Signal=ADCx_INP3
PA7.Signal=LTDC_R4
PA8.Signal=LTDC_B6
PA9.Signal=LTDC_B5
PB1.Signal=ADCx_INP5
PB10.Signal=LTDC_G7
PB11.Signal=LTDC_G6
PB12.Signal=LTDC_G5
PB13.Signal=LTDC_G4
PB14.Signal=SDMMC2_D0
PB15.Signal=SDMMC2_D1
PB3(JTDO/TRACESWO).Signal=DEBUG_JTDO-SWO
PB4(NJTRST).Signal=LTDC_R3
PB5.Signal=LTDC_R2
PB9.Signal=SPI2_NSS
PC1.Signal=SPI2_MOSI
PC10.Signal=SPI3_SCK
PC11.Signal=SPI3_MISO
PC12.Signal=SPI3_MOSI
PC14-OSC32_IN(OSC32_IN).Signal=RCC_OSC32_IN
PC15-OSC32_OUT(OSC32_OUT).Signal=RCC_OSC32_OUT
PC2.Signal=SPI2_MISO
PC3.Signal=S_TIM1_CH2
PC4.Signal=ADCx_INP4
PC9.Signal=I2S_CKIN
PD15.Signal=LPTIM5_OUT
PD3.Signal=SPI2_SCK
PD6.Signal=SDMMC2_CK
PD7.Signal=SDMMC2_CMD
PE0.Signal=UART8_RX
PE1.Signal=UART8_TX
PE11.Signal=LTDC_VSYNC
PE13.Signal=S_TIM1_CH3
PE2.Signal=SAI1_MCLK_A
PE4.Signal=SAI1_FS_A
PE5.Signal=SAI1_SCK_A
PE6.Signal=SAI1_SD_A
PE8.Signal=UART7_TX
PE9.Signal=S_TIM1_CH1
PF0.Signal=I2C2_SDA
PF1.Signal=I2C2_SCL
PF10.Signal=LTDC_R1
PF11.Signal=LTDC_B0
PF12.Signal=SPI5_MISO
PF13.Signal=SPI5_NSS
PF14.Signal=SPI5_MOSI
PF15.Signal=SPI5_SCK
PF6.Signal=UART7_RX
PF7.Signal=LTDC_G0
PF8.Signal=LTDC_G1
PF9.Signal=LTDC_R0
PG0.Signal=LTDC_R7
PG1.Signal=LTDC_R6
PG11.Signal=SDMMC2_D2
PG12.Signal=SDMMC2_D3
PG13.Signal=LTDC_CLK
PG14.Signal=LTDC_B1
PG2.Signal=LTDC_HSYNC
PH0-OSC_IN(PH0).Signal=RCC_OSC_IN
PH1-OSC_OUT(PH1).Signal=RCC_OSC_OUT

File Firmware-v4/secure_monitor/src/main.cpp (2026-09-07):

#include <cstdint>
#include "gkos_boot_interface.h"
#include "logger.h"
#include "osspinlock.h"
#include "vmem.h"
#include "gkos_vmem.h"
#include "vblock.h"
#include "sm_clocks.h"
#include "clocks.h"
#include "elf.h"
#include "gic.h"
#include "ap.h"
#include "pmic.h"

#define STACK_SIZE  65536

uint64_t mp_stack_vaddr;
uint64_t ap_stack_vaddr;

uint64_t ddr_start;
uint64_t ddr_end;

uint64_t vaddr_ptr;

gkos_boot_interface gbi_for_el1;

gkos_boot_interface::board_type btype;

AP_Data aps[ncores] = { 0 };

static inline uint64_t align(uint64_t v)
{
    return (v + 65535ULL) & ~65535ULL;
}

extern "C" uint64_t mp_preinit(const gkos_boot_interface *gbi)
{
    /* This is called prior to __libc_init_array so cannot rely on global objects being inited */

    // Get end of virtual space
    extern int _ebss;
    vaddr_ptr = (uint64_t)&_ebss;
    vaddr_ptr = align(vaddr_ptr);

    // Get stack space for mp and ap with guard pages before, between, after
    auto stack_alloc = vmem_alloc(3 * 65536 + STACK_SIZE * 2);
    mp_stack_vaddr = stack_alloc + 65536;
    ap_stack_vaddr = stack_alloc + 65536 * 2 + STACK_SIZE;

    // pointers for the pmem alloc
    ddr_start = gbi->ddr_start;
    ddr_end = gbi->ddr_end;

    pmem_map_region(mp_stack_vaddr, STACK_SIZE, true, true);
    pmem_map_region(ap_stack_vaddr, STACK_SIZE, true, true);

    return mp_stack_vaddr + STACK_SIZE;
}

extern "C" uint64_t ap_preinit()
{
    return ap_stack_vaddr + STACK_SIZE;
}

extern "C" void mp_kmain(const gkos_boot_interface *gbi, uint64_t magic)
{
    klog("SM: startup\n");

    clock_takeover();

    if(gbi->btype != gkos_boot_interface::board_type::QEMU)
    {
        // determine board type
        auto pmic_prod_id = pmic_read_register(0);

        if(pmic_prod_id == 0x22)
        {
            btype = gkos_boot_interface::board_type::GKV4;
        }
        else if(pmic_prod_id == 0x20)
        {
            btype = gkos_boot_interface::board_type::EV1;
        }
        else
        {
            klog("SM: unknown product id: %x\n", pmic_prod_id);
            while(true);
        }
    }
    else
    {
        btype = gbi->btype;
    }

    // init el1 vmem
    init_vmem(1);
    epoint ept_el1;
    if(elf_load((const void *)0x60060000, &ept_el1, 1) != 0)
    {
        klog("SM: elf_load failed\n");
        while(true);
    }

    // make a stack for el1 and map into our namespace
    auto el1_stack_vaddr = vmem_alloc(65536);
    auto el1_stack_paddr = pmem_vaddr_to_paddr(el1_stack_vaddr, true, true, 3);
    auto el1_stack_vaddr_el1 = el1_stack_paddr + UH_START;

    // populate data for el1 (keep some space for us)
    gbi_for_el1.ddr_start = ddr_start + 8 * STACK_SIZE;
    gbi_for_el1.ddr_end = ddr_end;
    ddr_end = gbi_for_el1.ddr_start;    // adjust our allocator
    extern uint64_t clock_block_paddr;
    gbi_for_el1.cur_s = (volatile uint64_t *)(clock_block_paddr + 0xfe00ULL);
    gbi_for_el1.tim_ns_precision = (volatile uint64_t *)(clock_block_paddr + 0xfe00ULL + 8ULL);
    gbi_for_el1.btype = btype;

    auto gbi_vaddr_el1 = pmem_vaddr_to_paddr((uint64_t)&gbi_for_el1, false, false, 3) + UH_START;

    // put the above arguments on the el1 stack
    uint64_t el1_estack_ptr = ((uint64_t)el1_stack_vaddr + 65536);
    el1_estack_ptr -= 16;
    *reinterpret_cast<volatile uint64_t *>(el1_estack_ptr) = gbi_vaddr_el1;
    *reinterpret_cast<volatile uint64_t *>(el1_estack_ptr + 8) = gkos_sm_magic;

    // Move APs to waiting state
    extern uint64_t AP_Start;
    AP_Start = 1;

    // eret to el1
    __asm__ volatile (
        "mrs x0, S3_1_C15_C2_1\n"       // CPUECTRL_EL1
        "orr x0, x0, #(0x1 << 6)\n"     // SMPEN
        "msr S3_1_C15_C2_1, x0\n"

        "isb\n"
        "tlbi alle1is\n"
        "dsb ish\n"
        "isb\n"

        "mrs x0, sctlr_el1\n"
        "orr x0, x0, #(0x1 << 0)\n"     // M
        "orr x0, x0, #(0x1 << 2)\n"     // C
        "orr x0, x0, #(0x1 << 12)\n"    // I
        "msr sctlr_el1, x0\n"

        "mov x0, #(0x3 << 20)\n"
        "msr cpacr_el1, x0\n"   // disable trapping of neon/fpu instructions

        "msr sp_el1, %[el1_estack_vaddr_el1]\n"

        "mrs x0, scr_el3\n"
        "bfc x0, #62, #1\n"     // clear NSE (part of secure bits)
        "bfc x0, #18, #1\n"     // clear EEL2 (no EL2)
        "orr x0, x0, #(1 << 10)\n" // set RW (use A64 for EL1)
        //"orr x0, x0, #1\n"      // set NS (combined with NSE - EL0/1 is non-secure)
        "bfc x0, #0, #1\n"      // only seems to work for EL1 secure for some reason
        "msr scr_el3, x0\n"

        // disable interrupts for setting up spsr and elr, then re-enable them during the eret
        "msr daifset, #0xf\n"

        "mrs x0, spsr_el3\n"
        "bfc x0, #0, #4\n"      // clear M bits
        "orr x0, x0, #1\n"      // EL1 with sp_el1
        "orr x0, x0, #4\n"
        "bfc x0, #6, #3\n"      // clear AIF bits (re-enable interrupts on eret)
        "msr spsr_el3, x0\n"

        "msr elr_el3, %[el1_ept]\n"     // load return address

        "eret\n"
        : :
            [el1_estack_vaddr_el1] "r" (el1_stack_vaddr_el1 + 65536 - 16),
            [el1_ept] "r" (ept_el1)
        : "memory", "x0"
    );
}
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

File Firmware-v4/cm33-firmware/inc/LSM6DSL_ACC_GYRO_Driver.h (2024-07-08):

/**
 ******************************************************************************
 * @file    LSM6DSL_ACC_GYRO_driver.h
 * @author  MEMS Application Team
 * @version V1.5
 * @date    17-May-2016
 * @brief   LSM6DSL header driver file
 ******************************************************************************
 * @attention
 *
 * <h2><center>&copy; COPYRIGHT(c) 2017 STMicroelectronics</center></h2>
 *
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
 ******************************************************************************
 */

/* Define to prevent recursive inclusion -------------------------------------*/
#ifndef __LSM6DSL_ACC_GYRO_DRIVER__H
#define __LSM6DSL_ACC_GYRO_DRIVER__H

/* Includes ------------------------------------------------------------------*/
#include <stdint.h>
/* Exported types ------------------------------------------------------------*/

#ifdef __cplusplus
extern "C" {
#endif

//these could change accordingly with the architecture

#ifndef __ARCHDEP__TYPES
#define __ARCHDEP__TYPES

typedef unsigned char u8_t;
typedef unsigned short int u16_t;
typedef unsigned int u32_t;
typedef int i32_t;
typedef short int i16_t;
typedef signed char i8_t;

#endif /*__ARCHDEP__TYPES*/

/* Exported common structure --------------------------------------------------------*/

#ifndef __SHARED__TYPES
#define __SHARED__TYPES

typedef union{
	i16_t i16bit[3];
	u8_t u8bit[6];
} Type3Axis16bit_U;

typedef union{
	i16_t i16bit;
	u8_t u8bit[2];
} Type1Axis16bit_U;

typedef union{
	i32_t i32bit;
	u8_t u8bit[4];
} Type1Axis32bit_U;

typedef enum {
  MEMS_SUCCESS				=		0x01,
  MEMS_ERROR				=		0x00
} mems_status_t;

#endif /*__SHARED__TYPES*/

/* Exported macro ------------------------------------------------------------*/

/* Exported constants --------------------------------------------------------*/

/************** I2C Address *****************/

#define LSM6DSL_ACC_GYRO_I2C_ADDRESS_LOW   0xD4  // SAD[0] = 0
#define LSM6DSL_ACC_GYRO_I2C_ADDRESS_HIGH  0xD6  // SAD[0] = 1

/************** Who am I  *******************/

#define LSM6DSL_ACC_GYRO_WHO_AM_I         0x6A

/************** Device Register  *******************/

#define LSM6DSL_ACC_GYRO_FUNC_CFG_ACCESS  	0X01

#define LSM6DSL_ACC_GYRO_SENSOR_SYNC_TIME  	0X04
#define LSM6DSL_ACC_GYRO_SENSOR_RES_RATIO  	0X05

#define LSM6DSL_ACC_GYRO_FIFO_CTRL1  	0X06
#define LSM6DSL_ACC_GYRO_FIFO_CTRL2  	0X07
#define LSM6DSL_ACC_GYRO_FIFO_CTRL3  	0X08
#define LSM6DSL_ACC_GYRO_FIFO_CTRL4  	0X09
#define LSM6DSL_ACC_GYRO_FIFO_CTRL5  	0X0A

#define LSM6DSL_ACC_GYRO_DRDY_PULSE_CFG_G  	0X0B
#define LSM6DSL_ACC_GYRO_INT1_CTRL  	0X0D
#define LSM6DSL_ACC_GYRO_INT2_CTRL  	0X0E
#define LSM6DSL_ACC_GYRO_WHO_AM_I_REG  	0X0F
#define LSM6DSL_ACC_GYRO_CTRL1_XL  	0X10
#define LSM6DSL_ACC_GYRO_CTRL2_G  	0X11
#define LSM6DSL_ACC_GYRO_CTRL3_C  	0X12
#define LSM6DSL_ACC_GYRO_CTRL4_C  	0X13
#define LSM6DSL_ACC_GYRO_CTRL5_C  	0X14
#define LSM6DSL_ACC_GYRO_CTRL6_G  	0X15
#define LSM6DSL_ACC_GYRO_CTRL7_G  	0X16
#define LSM6DSL_ACC_GYRO_CTRL8_XL  	0X17
#define LSM6DSL_ACC_GYRO_CTRL9_XL  	0X18
#define LSM6DSL_ACC_GYRO_CTRL10_C  	0X19

#define LSM6DSL_ACC_GYRO_MASTER_CONFIG  	0X1A
#define LSM6DSL_ACC_GYRO_WAKE_UP_SRC  	0X1B
#define LSM6DSL_ACC_GYRO_TAP_SRC  	0X1C
#define LSM6DSL_ACC_GYRO_D6D_SRC  	0X1D
#define LSM6DSL_ACC_GYRO_STATUS_REG  	0X1E

#define LSM6DSL_ACC_GYRO_OUT_TEMP_L  	0X20
#define LSM6DSL_ACC_GYRO_OUT_TEMP_H  	0X21
#define LSM6DSL_ACC_GYRO_OUTX_L_G  	0X22
#define LSM6DSL_ACC_GYRO_OUTX_H_G  	0X23
#define LSM6DSL_ACC_GYRO_OUTY_L_G  	0X24
#define LSM6DSL_ACC_GYRO_OUTY_H_G  	0X25
#define LSM6DSL_ACC_GYRO_OUTZ_L_G  	0X26
#define LSM6DSL_ACC_GYRO_OUTZ_H_G  	0X27
#define LSM6DSL_ACC_GYRO_OUTX_L_XL  	0X28
#define LSM6DSL_ACC_GYRO_OUTX_H_XL  	0X29
#define LSM6DSL_ACC_GYRO_OUTY_L_XL  	0X2A
#define LSM6DSL_ACC_GYRO_OUTY_H_XL  	0X2B
#define LSM6DSL_ACC_GYRO_OUTZ_L_XL  	0X2C
#define LSM6DSL_ACC_GYRO_OUTZ_H_XL  	0X2D
#define LSM6DSL_ACC_GYRO_SENSORHUB1_REG  	0X2E
#define LSM6DSL_ACC_GYRO_SENSORHUB2_REG  	0X2F
#define LSM6DSL_ACC_GYRO_SENSORHUB3_REG  	0X30
#define LSM6DSL_ACC_GYRO_SENSORHUB4_REG  	0X31
#define LSM6DSL_ACC_GYRO_SENSORHUB5_REG  	0X32
#define LSM6DSL_ACC_GYRO_SENSORHUB6_REG  	0X33
#define LSM6DSL_ACC_GYRO_SENSORHUB7_REG  	0X34
#define LSM6DSL_ACC_GYRO_SENSORHUB8_REG  	0X35
#define LSM6DSL_ACC_GYRO_SENSORHUB9_REG  	0X36
#define LSM6DSL_ACC_GYRO_SENSORHUB10_REG  	0X37
#define LSM6DSL_ACC_GYRO_SENSORHUB11_REG  	0X38
#define LSM6DSL_ACC_GYRO_SENSORHUB12_REG  	0X39
#define LSM6DSL_ACC_GYRO_FIFO_STATUS1  	0X3A
#define LSM6DSL_ACC_GYRO_FIFO_STATUS2  	0X3B
#define LSM6DSL_ACC_GYRO_FIFO_STATUS3  	0X3C
#define LSM6DSL_ACC_GYRO_FIFO_STATUS4  	0X3D
#define LSM6DSL_ACC_GYRO_FIFO_DATA_OUT_L  	0X3E
#define LSM6DSL_ACC_GYRO_FIFO_DATA_OUT_H  	0X3F
#define LSM6DSL_ACC_GYRO_TIMESTAMP0_REG  	0X40
#define LSM6DSL_ACC_GYRO_TIMESTAMP1_REG  	0X41
#define LSM6DSL_ACC_GYRO_TIMESTAMP2_REG  	0X42

#define LSM6DSL_ACC_GYRO_TIMESTAMP_L  	0X49
#define LSM6DSL_ACC_GYRO_TIMESTAMP_H  	0X4A

#define LSM6DSL_ACC_GYRO_STEP_COUNTER_L  	0X4B
#define LSM6DSL_ACC_GYRO_STEP_COUNTER_H  	0X4C

#define LSM6DSL_ACC_GYRO_SENSORHUB13_REG  	0X4D
#define LSM6DSL_ACC_GYRO_SENSORHUB14_REG  	0X4E
#define LSM6DSL_ACC_GYRO_SENSORHUB15_REG  	0X4F
#define LSM6DSL_ACC_GYRO_SENSORHUB16_REG  	0X50
#define LSM6DSL_ACC_GYRO_SENSORHUB17_REG  	0X51
#define LSM6DSL_ACC_GYRO_SENSORHUB18_REG  	0X52

#define LSM6DSL_ACC_GYRO_FUNC_SRC  	0X53
#define LSM6DSL_ACC_GYRO_TAP_CFG1  	0X58
#define LSM6DSL_ACC_GYRO_TAP_THS_6D  	0X59
#define LSM6DSL_ACC_GYRO_INT_DUR2  	0X5A
#define LSM6DSL_ACC_GYRO_WAKE_UP_THS  	0X5B
#define LSM6DSL_ACC_GYRO_WAKE_UP_DUR  	0X5C
#define LSM6DSL_ACC_GYRO_FREE_FALL  	0X5D
#define LSM6DSL_ACC_GYRO_MD1_CFG  	0X5E
#define LSM6DSL_ACC_GYRO_MD2_CFG  	0X5F

#define LSM6DSL_ACC_GYRO_OUT_MAG_RAW_X_L  	0X66
#define LSM6DSL_ACC_GYRO_OUT_MAG_RAW_X_H  	0X67
#define LSM6DSL_ACC_GYRO_OUT_MAG_RAW_Y_L  	0X68
#define LSM6DSL_ACC_GYRO_OUT_MAG_RAW_Y_H  	0X69
#define LSM6DSL_ACC_GYRO_OUT_MAG_RAW_Z_L  	0X6A
#define LSM6DSL_ACC_GYRO_OUT_MAG_RAW_Z_H  	0X6B

#define LSM6DSL_ACC_GYRO_X_OFS_USR  	0X73
#define LSM6DSL_ACC_GYRO_Y_OFS_USR  	0X74
#define LSM6DSL_ACC_GYRO_Z_OFS_USR  	0X75
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

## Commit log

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2024-09-23 dont crash on tilt_enable(false)
    [lsm_driver.cpp]
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2024-09-29 fix error where we may try to allocate an area too large for this buddy
    [buddy.h]
2024-09-29 fix gpu framebuffer addresses
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2024-09-30 fix vcap resistor divider
    [power.kicad_sch]
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2024-10-09 hardware changes
    [mcub.kicad_sch, memory.kicad_sch]
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2024-10-13 disable uart/swo debug for now - too much waiting on slow interfaces
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2024-10-14 pcb updates
    [mcua.kicad_sch, mcub.kicad_sch]
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2024-10-14 fix dma channel reset
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2024-10-29 redesign for better signal integrity
    [audio.kicad_sch, gk-pcbv3.kicad_sch, gk-pcbv3.step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]
2024-11-02 Route top end of board Remove vbat stat LED
    [gk-pcbv3.kicad_sch, mcua.kicad_sch]
2024-11-02 gerbers for v3.1
    [gk-pcbv3-B_Cu.gbl, gk-pcbv3-B_Mask.gbs, gk-pcbv3-B_Paste.gbp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]
2024-11-02 remove step file, use 2d image instead
    [gk-pcbv3.step]
2024-11-11 case parts
    [bottom panel.stl, button dir extender up.stl, button dir.stl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]
2024-11-11 add decal to top panel
    [top panel.stl]
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2024-11-24 reduce solder paste areas for stencils
    [gk-pcbv3-B_Cu.gbl, gk-pcbv3-B_Mask.gbs, gk-pcbv3-B_Paste.gbp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]
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2024-12-02 Fix memcheck error where we may ask for 4 bytes at 97fffff
    [main.cpp]
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2024-12-02 add diode into battery charger
    [gk-pcbv3.kicad_sch]
2024-12-02 fixup clocks push hyperram to 192 MHz
    [gk-pcbv3.ioc]
2024-12-04 fix typos in adc config add in vref monitoring
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2024-12-14 add comment for getting battery to work
    [gk-pcbv3.kicad_sch]
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2024-12-26 begin wifi integration
    [gk-pcbv3.kicad_sch, interface.kicad_sch]
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2025-01-04 updated stl models
    [bottom panel.stl, d pad support.stl, top panel.stl]
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2025-01-06 add tilt task have i2c commands return errors on failure
    [LSM6DSL_ACC_GYRO_Driver.h, ctp.cpp, lsm_driver.cpp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]
2025-01-07 update schematics for new vreg design
    [audio.kicad_sch, gk-pcbv3.kicad_sch, interface.kicad_sch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]
2025-01-11 new gerbers
    [gk-pcbv3-B_Cu.gbl, gk-pcbv3-B_Mask.gbs, gk-pcbv3-B_Paste.gbp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]
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2025-01-13 stl changes add bom
    [button dir extender up.stl, button dir.stl, button power.stl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]
2025-01-18 new dpad and power buttons
    [button power.stl, dpad.stl]
2025-01-18 new top + bottom panels
    [bottom panel.stl, top panel.stl]
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2025-01-21 begin moving files across
    [code-format.cfg]
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2025-02-01 fix power monitor for new battery charger
    [main.cpp]
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2025-02-08 don't use hse for rtc in case of lse failure, instead simply return default values when reading rtc. The issue is that RCC->BDCR can only have 0 written by an entire backup domain reset, thus we cann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
2025-02-08 reset thread counters on each run of rtos plugin so we get up to date cpu usage
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2025-02-12 dump raw lsm values use to fix pitch calculation
    [lsm_driver.cpp]
2025-02-15 fix temperature reading in case calibration values are from a NTC
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2025-02-16 new bottom panel models
    [bottom panel.stl, bumper button.stl]
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2025-02-22 new bottom case models
    [bottom panel.stl, bumper button.stl]
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2025-04-15 set tilt axes to zero if lsm init failed
    [lsm_driver.cpp]
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2025-08-13 Add TODOs to schematic Update to Kicad 9
    [audio.kicad_sch, gk-pcbv3.kicad_sch, interface.kicad_sch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]
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2025-08-25 add TODO
    [gk-pcbv3.kicad_sch]
2025-08-27 update pcb TODO
    [gk-pcbv3.kicad_sch]
2025-10-26 first commit of stm32mp2 version gkv4
    [audio.kicad_sch, gk-pcbv3.kicad_sch, gk.kicad_sch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]
2025-10-26 update silkscreen text
    [mpu1.kicad_sch, screen.kicad_sch]
2025-10-27 add controls daughterboard for v4
    [buttons.kicad_sch, gk-controls.kicad_pcb, gk-controls.kicad_sch]
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2025-10-27 board 3d exports
    [gk-controls.step, gk.step]
2025-10-27 add back-side 10 pin debug header
    [mpu_misc.kicad_sch]
2025-10-28 adjust ground fills around oscillators
2025-10-28 update ground fills
    [gk-controls.kicad_pcb]
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2025-11-02 remove wfi for AP - it doesn't actually get any interrupts
2025-11-02 Add UART6 out for debug
    [mpu_ddr_pins.kicad_sch, mpu_misc.kicad_sch]
2025-11-03 Add heap Wrap memcpy/memmove to prevent them performing unaligned accesses
    [main.cpp]
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2025-11-06 add option for larger qspi flash
    [mpu_flashsd.kicad_sch]
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2025-11-15 pcb order 20251115
    [audio.kicad_sch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]
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2025-12-01 Change HSE to 40 MHz as per EV1
    [mpu_misc.kicad_sch]
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2025-12-08 keep reset bits in sctlr
    [main.cpp]
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2025-12-11 it works! shared_ptr has two separate concurrency mechanisms 1) through Lock policy _S_atomic et al - these are enabled by __GTHREADS and _GLIBCXX_HAVE_ATOMIC_LOCK_POLICY 2) via gthr which defaults t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
2025-12-14 add process/thread return values - stored in completion_lists fix condition tout not being zero-initialized
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2025-12-19 add bootinfo.h fix max_screen_width various changes to try and get sai working
    [main.cpp]
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2025-12-23 add more errata
    [gk.kicad_sch]
2025-12-27 update pin name
    [mpu1.kicad_sch]
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2025-12-29 add errata
    [gk.kicad_sch]
2025-12-29 update errata
    [gk.kicad_sch]
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2026-01-04 add Eigen and EKF module
    [gk.kicad_sch]
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2026-01-04 enable mmu to avoid alignment errors
    [main.cpp]
2026-01-04 fix typo in fdt calculation
    [lsm_driver.cpp]
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2026-01-10 update errata
    Former-commit-id: e468e7c5ad440b5d45592638cc8c36d486294332
    [gk.kicad_sch]
2026-01-10 set up ospi dpi mode. qpi not working yet. Add tuning of delay block.
    Former-commit-id: fe7c2da7404156004244cf43360c05aad4190853
    [gk.kicad_sch]
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2026-01-16 Add memchk to dump illegal access errors Provide R/W priv/unpriv access to DDR Allow vmem_to_pmem_quick to check other address spaces Add focus process Pass regs structure and elr_el1 to gic interrup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
    [main.cpp]
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2026-01-19 fix press/release wrong way round
    [main.cpp]
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2026-01-24 fix use of processlist rathet than threadlist
2026-01-24 more thread exit fixes
2026-01-24 fix race condition in thread cleanup
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2026-01-26 invert joystick y axes for what sdl expects
    [main.cpp]
2026-01-26 invert y axis for digital stick
    [main.cpp]
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2026-01-28 fix is_blocking: it was clearing the block_until member appropriately but not others therefore thread remained blocking
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2026-01-30 fix dma accesses not being secure
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2026-02-02 update pcb step model
    [gk.step]
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2026-02-03 First screen support prototype
    [screen_support_v4.stl]
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2026-02-07 fix various compiler warnings highlighted by enabling optimizations
    [i2c.cpp]
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2026-02-17 fix string printing
2026-02-17 fix interrupts
2026-02-17 ensure ctp reset after every failed check_mem_data
    [ctp.cpp]
2026-02-22 add v2 controls board
    [buttons.kicad_sch, gk-controls.kicad_pcb, gk-controls.kicad_sch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]
2026-02-22 nudge btnleds up to the appropriate spot
    [gk-controls.kicad_pcb]
2026-02-22 controls 3d model
    [gk-controls.step]
2026-02-22 bring across board outline from fusion
    [v2 pcb outline.dxf]
2026-02-22 update drill holes
    [gk.kicad_sch]
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2026-02-22 remove wilc chip
    [gk.kicad_sch]
2026-02-22 add usart6 connection to schematic
    [gk.kicad_sch, mpu_ddr_pins.kicad_sch, mpu_flashsd.kicad_sch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]
2026-02-22 Remove wakeupn mosfets in schematic
    [gk.kicad_sch, mpu_misc.kicad_sch, power.kicad_sch]
2026-02-22 update ctp irq resistor divider
    [gk.kicad_sch, screen.kicad_sch]
2026-02-22 fix tps2051 schematic
    [gk.kicad_sch, interface.kicad_sch]
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2026-02-22 turn back battery connectors sideways add notch for battery cables looping round from front
    [gk.kicad_sch, power.kicad_sch]
2026-02-22 add i2c test points
    [gk.kicad_sch]
2026-02-22 add test points to power planes
    [gk.kicad_sch, interface.kicad_sch, power.kicad_sch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]
2026-02-22 move ctp connector north 2 mm
    [gk.kicad_sch]
2026-02-22 add bq25601 battery charger as alternative
    [gk.kicad_sch, power.kicad_sch]
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2026-02-22 move LB/RB to main board
    [gk.kicad_sch, interface.kicad_sch, mpu_flashsd.kicad_sch]
2026-02-23 update pcb routing based on new v2 changes
    [interface.kicad_sch, mpu_misc.kicad_sch, power.kicad_sch]
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2026-02-23 New DDR routing taking into account die lengths and impedance
    [gk.kicad_sch]
2026-02-23 fix SPKR_NSD pin
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2026-02-25 Add cm33 klog Fix * width/precision specifier in logger_vprintf
    [i2c.cpp, main.cpp]
2026-02-25 fix ctp cm33 interrupts
    [ctp.cpp]
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2026-03-08 add case for v2 pcbs
    [button_back.stl, button_dpad.stl, button_front.stl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]
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2026-03-08 remove hole in paste layer for h1
    [gk-controls.kicad_pcb]
2026-03-08 fix incorrect inp4 pin
    [adc.cpp, main.cpp]
2026-03-10 begin adding breakout board for triggers
    [buttons.kicad_sch, gk-controls-trigger.kicad_pcb, gk-controls-trigger.kicad_sch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]
2026-03-10 add v3 control board and trigger daughterboard
    [buttons.kicad_sch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]
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2026-03-11 if LSM6DSL_EN is low then the tilt sensor pulls the entire i2c1 bus low and prevents communication with the io expander. Therefore only use it for reset.
    [lsm_driver.cpp]
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2026-03-15 fix max17048 i2c address
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2026-03-16 buttons with 50um smaller dimensions
    [back button.stl, dpad button.stl, front button.stl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]
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2026-03-17 add crow inlay for front panel button
    [front_button_crow_inlay.stl, front_button_crow_mask.stl, front_button_crow_mask_top.stl]
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2026-03-22 add new case top stl
    [gkv4-top.stl]
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2026-04-04 more etnaviv work - device now initialises correctly
2026-04-05 fix iommu mappings not being added to context->mappings for the fixed alloc case
2026-04-06 switch to using a FixedQueue<> for GPU event assignment
2026-04-09 fix fence lists growing with each frame - now averages 2000 fps+ on sdlgl_test
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2026-04-18 have power button reboot the system if in rawsd mode
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2026-04-25 reduce use of PProcess throughout, replace with Process if it is the current one because it will never go out of scope if the process is executing
    This helps reduce dangling PProcess's if a thread is killed as part of process kill, and therefore ensures ~Process() gets called to reap memory
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2026-05-02 fix dma_free_wc to make sure we don't try to release owned_pages in the cleanup thread and make sure of kernel/user split
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2026-05-17 prevent double close of ntpc socket
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2026-05-27 ssbl startup delay only if reboot via NRST or via CPU
    [main.cpp]
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2026-06-08 fix syscall_kill killing the current thread before it completes
2026-06-13 fail ext4 mount on recover/journal_start fail so we can drop into rawsd mode
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2026-09-07 Fix typos in initial tcr_el1 setup by sm.
    [main.cpp]
2026-09-07 add missing clobbered register to start_ap
    [main.cpp]
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
